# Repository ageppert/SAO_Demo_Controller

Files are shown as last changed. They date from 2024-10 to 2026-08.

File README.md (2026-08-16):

# SAO DEMO CONTROLLER

A Microcontroller for your smarter-than-average SAO!

The SAO Demo Controller makes it convenient to bring life to your advanced I2C-based SAO! Use this to test and demonstrate your new design even when your host badge isn't ready to control the SAO. Maybe this is better referred to as a micro badge for developing SAOs.

CAUTION: Do not plug this into your host badge and USB-C at the same time!!!

Follow this project at: https://hackaday.io/project/198034-sao-demo-controller 

Hardware Version 3.X
This one is protected for multiple power input options simultaneously with far more advanced power options, protection, and routing. This one is a perfect companion for an Etch sAo Sketch, Mac SAO, or any other SAO! See schematic for details and instructions.

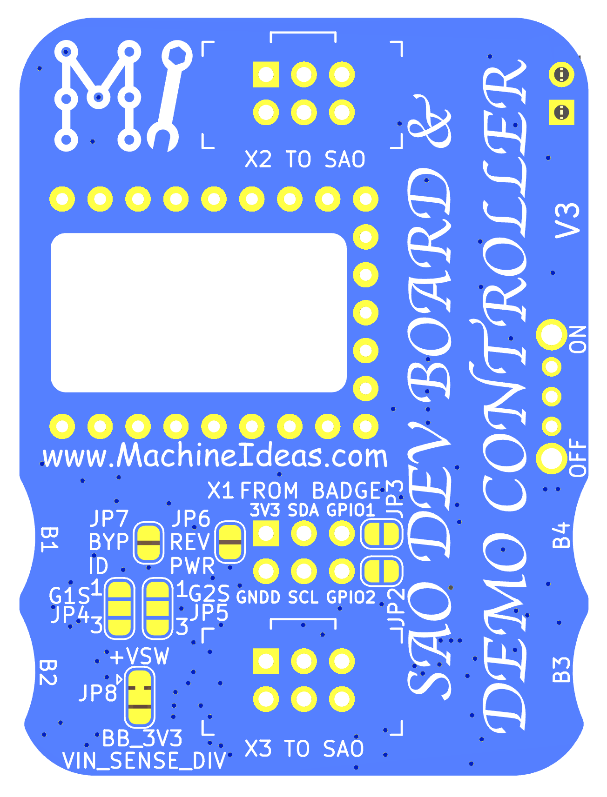
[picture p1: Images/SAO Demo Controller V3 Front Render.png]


Hardware Version 2.0 

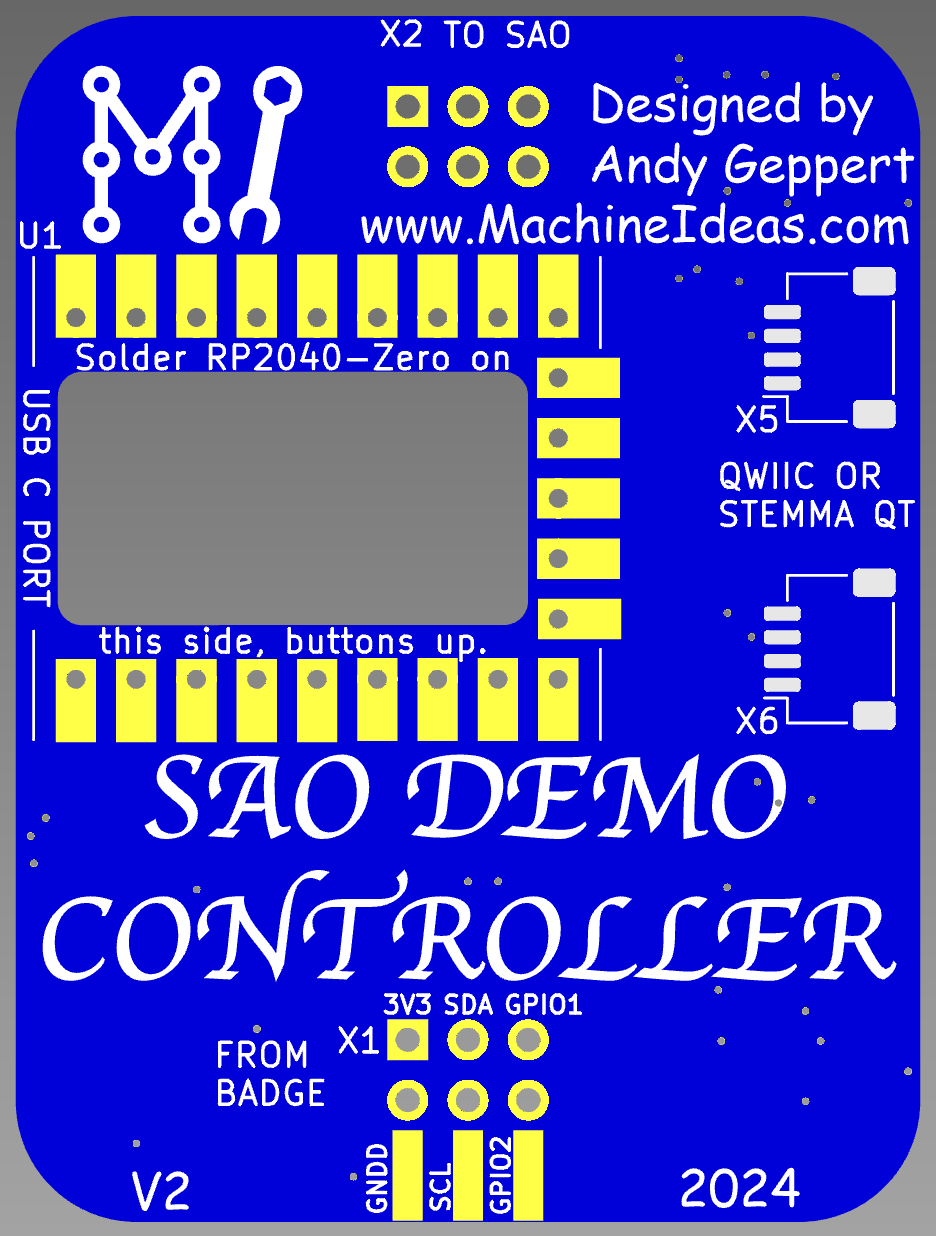
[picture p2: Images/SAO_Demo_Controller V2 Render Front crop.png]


Hardware Version 1.0 

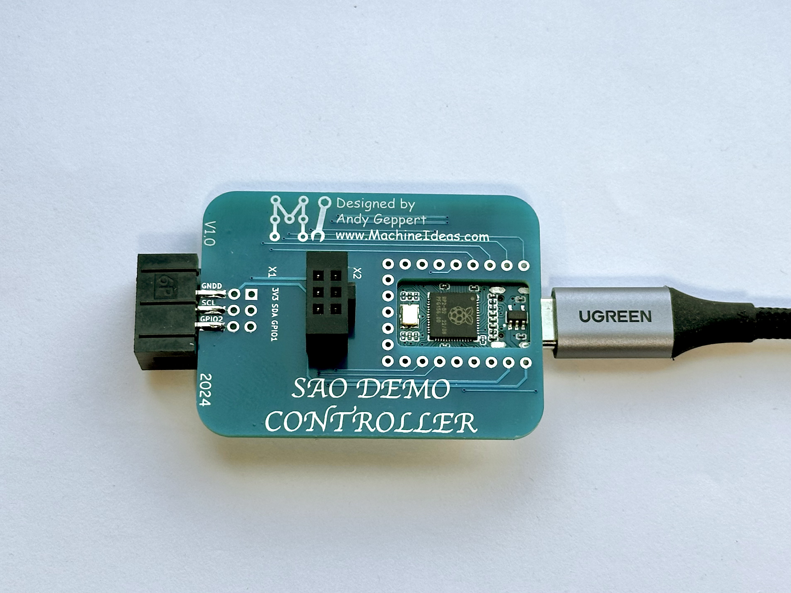
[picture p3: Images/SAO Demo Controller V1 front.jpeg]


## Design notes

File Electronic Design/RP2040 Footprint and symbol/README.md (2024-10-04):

# RP2040-Zero-KiCAD
KiCAD footprint and symbol for the RP2040 Zero

Currently untested! Use at your own risk. Pin numbers are kind of arbitrary since I couldn't find any official pin labels, so I put pin 1 at the top left. 

FROM: https://github.com/dj505/RP2040-Zero-KiCAD

MODIFIED AND TESTED: Andy Geppert, 2024

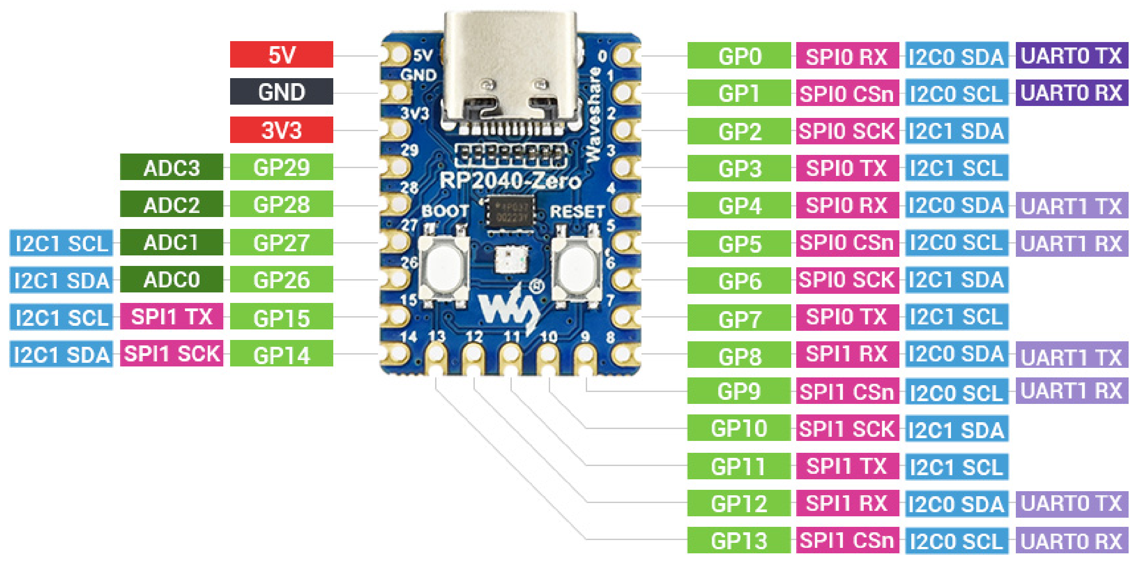
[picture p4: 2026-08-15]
Images/RP2040-Zero Pinout (top).png

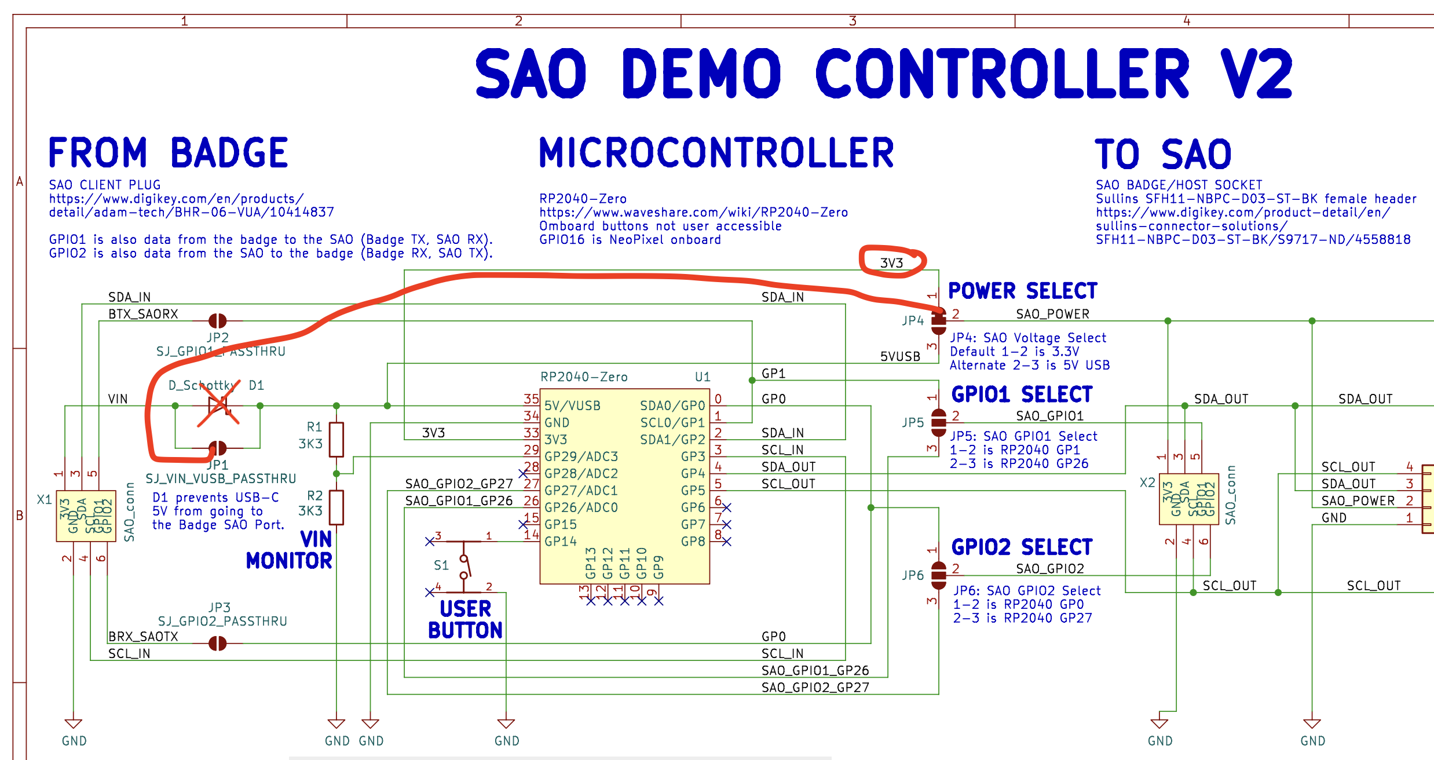
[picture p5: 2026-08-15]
Images/SAO Demo Controller mod for I2C1 on bottom schematic.png

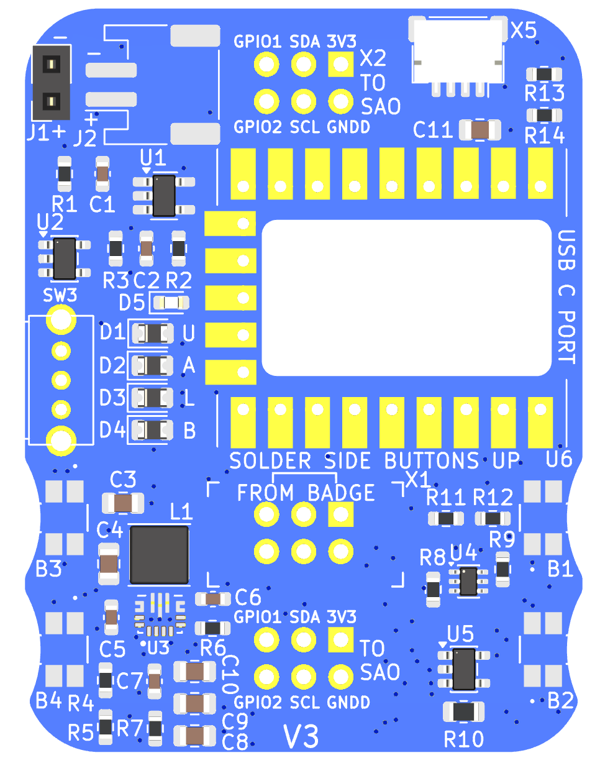
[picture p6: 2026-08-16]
Electronic Design/SAO Demo Controller V3 Schematic and Renders/SAO Demo Controller V3 Back Render.png

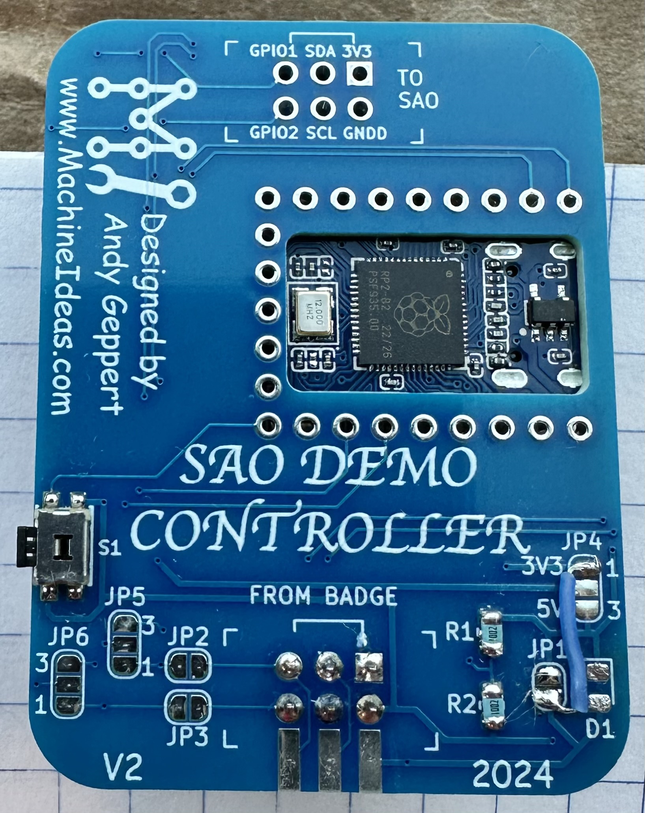
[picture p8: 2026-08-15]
Images/SAO Demo Controller mod for I2C1 on bottom pic.jpeg

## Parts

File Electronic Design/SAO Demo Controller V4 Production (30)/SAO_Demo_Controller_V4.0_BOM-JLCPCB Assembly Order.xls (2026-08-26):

JLCPCB BOM Tool - BOM Matching
BOM name：SAO_Demo_Controller_V4.0_bom-JLCPCB Assembly Order.xlsx |  |  | Download Time：2026-08-23 09:54:16 |  |  |  | * Our matching results are updated in real-time, but stock and prices may change. If it's been over 24 hours, please re-match before placing your order.
PCB Assembled Qty：30 |  |  | Est. Total Price：133.5422
Your BOM |  |  |  | Matched Parts |  |  |  |  |  |  | Order Information
Designator | Comment | Footprint | JLCPCB Part # | Matches | Part # | Manufacturer | Footprint | Description | Category | Warning | JLCPCB Part # | Product link | Lib Type | Qty | Source | Total Price ($)
B1,B2,B3,B4 | EVQP7J01P | SMD4_SW_EVQP7J_PAN |  | Select by System | EVQP7J01P | PANASONIC | SMD,3.6x3.5mm | -20℃~+70℃ 1.35mm 1.6N 100,000 cycles 12V 3.55mm 3.5mm 50mA Black Rectangular Button SMD(SMT) Tab SPST Surface Mount, Right Angle Without Bracket SMD,3.6x3.5mm Tactile Switches ROHS | Tactile Switches |  | C2828254 | https://jlcpcb.com/partdetail/PANASONIC-EVQP7J01P/C2828254 | Extended | 122 | 122 JLCPCB | 26.0348
C1,C5,C6 | 100nF | 0603 |  | Select by System | CC0603KRX7R9BB104 | YAGEO | 0603 | 100nF 50V X7R ±10% 0603 Multilayer Ceramic Capacitors MLCC - SMD/SMT ROHS | Multilayer Ceramic Capacitors MLCC - SMD/SMT |  | C14663 | https://jlcpcb.com/partdetail/YAGEO-CC0603KRX7R9BB104/C14663 | Basic | 100 | 100 JLCPCB | 1.5
C2,C7 | 10uF | 0603 |  | Select by System | CL10A106KP8NNNC | Samsung Electro-Mechanics | 0603 | 10V 10uF X5R ±10% 0603 Multilayer Ceramic Capacitors MLCC - SMD/SMT ROHS | Multilayer Ceramic Capacitors MLCC - SMD/SMT |  | C19702 | https://jlcpcb.com/partdetail/20411-CL10A106KP8NNNC/C19702 | Basic | 70 | 70 JLCPCB | 2.541
C3,C4 | 47uF | 0805 |  | Select by System | CL21A476MQYNNNE | Samsung Electro-Mechanics | 0805 | 47uF 6.3V X5R ±20% 0805 Multilayer Ceramic Capacitors MLCC - SMD/SMT ROHS | Multilayer Ceramic Capacitors MLCC - SMD/SMT |  | C16780 | https://jlcpcb.com/partdetail/17464-CL21A476MQYNNNE/C16780 | Basic | 66 | 66 JLCPCB | 11.5632
D1 | LED | 0603 |  | Select by System | KT-0603R | Hubei KENTO Elec | 0603 | -40℃~+85℃ 1.6mm x 0.8mm square LED 1.8V~2.4V 120° 20mA 300mcd 40mW 615nm~630nm 645nm Discrete Diode Red Water Clear 0603 LED Indication - Discrete ROHS | LED Indication - Discrete |  | C2286 | https://jlcpcb.com/partdetail/Hubei_KENTOElec-KT0603R/C2286 | Basic | 40 | 40 JLCPCB | 0.296
J2 | BAT-L | JST_PH_S2B-PH-SM4-TB_1x02-1MP_P2.00mm_Horizontal |  | Select by System | S2B-PH-SM4-TB(LF)(SN) | JST | SMD,P=2mm,卧贴 | -25℃~+85℃ 1 100V 1x2P 2 2A 2P 2mm 5.5mm 7.9mm 8.6mm Auxiliary Solder Pin Beige Copper alloy PA PH Surface Mount, Right Angle Tin UL94V-0 SMD,P=2mm,卧贴 Wire To Board Connector ROHS | Wire To Board Connector |  | C295747 | https://jlcpcb.com/partdetail/JST-S2B_PH_SM4_TB_LF_SN/C295747 | Extended | 30 | 30 JLCPCB | 6.495
L1 | 2.2uH | L_Sunlord_SWPA4020S |  | Select by System | SLW4018S2R2MST | Sunltech Tech | SMD,4x4mm | 1.65A 2.2uH 2.7A 45mΩ Magnetic Shielded Inductor ±20% SMD,4x4mm Power Inductors ROHS | Power Inductors |  | C206341 | https://jlcpcb.com/partdetail/SunltechTech-SLW4018S2R2MST/C206341 | Extended | 34 | 34 JLCPCB | 1.0608
R1,R15,R18,R4,R5,R6,R7 | 1K | 0603 |  | Select by System | 0603WAF1001T5E | UNI-ROYAL(Uniroyal Elec) | 0603 | -55℃~+155℃ 100mW 1kΩ 75V Thick Film Resistor ±1% ±100ppm/℃ 0603 Chip Resistor - Surface Mount ROHS | Chip Resistor - Surface Mount |  | C21190 | https://jlcpcb.com/partdetail/21904-0603WAF1001T5E/C21190 | Basic | 220 | 220 JLCPCB | 1.496
R2 | 1K2 | 0603 |  | Select by System | 0603WAF1201T5E | UNI-ROYAL(Uniroyal Elec) | 0603 | -55℃~+155℃ 1.2kΩ 100mW 75V Thick Film Resistor ±1% ±100ppm/℃ 0603 Chip Resistor - Surface Mount ROHS | Chip Resistor - Surface Mount |  | C22765 | https://jlcpcb.com/partdetail/23492-0603WAF1201T5E/C22765 | Basic | 40 | 40 JLCPCB | 0.252
R8,R9 | 2K2 | 0603 |  | Select by System | 0603WAF2201T5E | UNI-ROYAL(Uniroyal Elec) | 0603 | -55℃~+155℃ 100mW 2.2kΩ 75V Thick Film Resistor ±1% ±100ppm/℃ 0603 Chip Resistor - Surface Mount ROHS | Chip Resistor - Surface Mount |  | C4190 | https://jlcpcb.com/partdetail/4597-0603WAF2201T5E/C4190 | Basic | 70 | 70 JLCPCB | 0.287
R10 | 0 | 0603 |  | Select by System | 0603WAF0000T5E | UNI-ROYAL(Uniroyal Elec) | 0603 | -55℃~+155℃ 0Ω 100mW 75V Thick Film Resistor ±1% 0603 Chip Resistor - Surface Mount ROHS | Chip Resistor - Surface Mount |  | C21189 | https://jlcpcb.com/partdetail/21903-0603WAF0000T5E/C21189 | Basic | 40 | 40 JLCPCB | 0.156
R12 | 1.2M | 0603 |  | Select by System | 0603WAF1204T5E | UNI-ROYAL(Uniroyal Elec) | 0603 | 1.2MΩ ±1% 0603 Chip Resistor - Surface Mount ROHS | Chip Resistor - Surface Mount |  | C22766 | https://jlcpcb.com/partdetail/23493-0603WAF1204T5E/C22766 | Extended | 40 | 40 JLCPCB | 0.072
R13 | 210K | 0603 |  | Select by System | CQ03WAF2103T5E | UNI-ROYAL(Uniroyal Elec) | 0603 | -55℃~+155℃ 100mW 210kΩ Thick Film Resistor ±1% 0603 Chip Resistor - Surface Mount ROHS |  |  | C50670454 | https://jlcpcb.com/partdetail/53304519-CQ03WAF2103T5E/C50670454 | Extended | 36 | 36 JLCPCB | 0.0648
R14,R16 | 8K2 | 0603 |  | Select by System | 0603WAF8201T5E | UNI-ROYAL(Uniroyal Elec) | 0603 | -55℃~+155℃ 100mW 75V 8.2kΩ Thick Film Resistor ±1% ±100ppm/℃ 0603 Chip Resistor - Surface Mount ROHS | Chip Resistor - Surface Mount |  | C25981 | https://jlcpcb.com/partdetail/26724-0603WAF8201T5E/C25981 | Basic | 70 | 70 JLCPCB | 0.455
R17 | 0.05-1% | 0805 |  | Select by System | LRE0805-2CR050F5 | RALEC | 0805 | 500mW 50mΩ Alloy Resistor SMD ±1% 0805 Current Sense Resistors / Shunt Resistors ROHS | Current Sense Resistors / Shunt Resistors |  | C5141277 | https://jlcpcb.com/partdetail/RALEC-LRE08052CR050F5/C5141277 | Extended | 34 | 34 JLCPCB | 2.2338
R19,R20,R3 | 4K7 | 0603 |  | Select by System | 0603WAF4701T5E | UNI-ROYAL(Uniroyal Elec) | 0603 | -55℃~+155℃ 100mW 4.7kΩ 75V Thick Film Resistor ±1% ±100ppm/℃ 0603 Chip Resistor - Surface Mount ROHS | Chip Resistor - Surface Mount |  | C23162 | https://jlcpcb.com/partdetail/23889-0603WAF4701T5E/C23162 | Basic | 100 | 100 JLCPCB | 0.3
SW3 | SK12D07L4B | Switch_SK12D07VG4 |  | Select by System | SK12D07L4B | XKB Connection | 插件,8.6x4.5mm | -20℃~+80℃ 10000 times 300mA 4.5mm 4.7mm 50V 8.6mm Black PC Pin Rectangular Columnar SPDT 插件,8.6x4.5mm Slide Switches ROHS | Slide Switches |  | C480340 | https://jlcpcb.com/partdetail/XKBConnection-SK12D07L4B/C480340 | Extended | 30 | 30 JLCPCB | 2.973
U1 | RY2201 | SOT-23-5_HandSoldering |  | Select by System | RY2201 | RYCHIP Semiconductor Inc. | SOT-23-5 | -40℃~+85℃ 1 100nA 2.4V 3A Lithium Battery Not supported Protection IC Support SOT-23-5 Battery Management ROHS | Battery Management |  | C370889 | https://jlcpcb.com/partdetail/RYCHIP_Semiconductor_Inc-RY2201/C370889 | Extended | 34 | 34 JLCPCB | 0.8738
U2 | TP4054 | SOT-23-5 |  | Select by System | TP4054-42-SOT25R | TOPPOWER(Nanjing Extension Microelectronics) | SOT-23-5 | -40℃~+85℃ 1 4.2V 450mA 45uA 4V~9V Charging IC Lithium Battery Not supported Not supported SOT-23-5 Battery Management ROHS | Battery Management |  | C32574 | https://jlcpcb.com/partdetail/33539-TP4054_42SOT25R/C32574 | Extended | 32 | 32 JLCPCB | 5.5904
U3,U4,U5,U6,U8 | LM66100DCK | SOT-363_SC-70-6 |  | Select by System | LM66100DCKR | Texas Instruments | SC-70-6 | -40℃~+125℃ 1 1.5A 1.5V~5.5V 150nA 95mΩ Integrated FET Reverse current blocking、Reverse polarity protection、With enable SC-70-6 ORing Controllers ROHS | Power Distribution Switches |  | C2869734 | https://jlcpcb.com/partdetail/TexasInstruments-LM66100DCKR/C2869734 | Extended | 150 | 150 JLCPCB | 26.025
U7 | TPS61200DRC | Texas_S-PVSON-N10_ThermalVias |  | Select by System | TPS61200DRCR | Texas Instruments | VSON-10-EP(3x3) | -40℃~+85℃@(TA) 1 1.65MHz 1.8V~5.5V 300mV~5.5V 70uA Adjustable Boost Boost Built-in Yes VSON-10-EP(3x3) DC-DC Converters ROHS | DC-DC Converters |  | C140320 | https://jlcpcb.com/partdetail/TexasInstruments-TPS61200DRCR/C140320 | Extended | 30 | 30 JLCPCB | 32.694
U9 | INA180A2 | SOT-23-5 |  | Select by System | INA180A2IDBVR(LX) | lingxingic | SOT-23-5 | -200mV~30V -40℃~+125℃ 1 100dB 175uA 1uV/℃ 2.7V~5.5V 210kHz 25uV 40nV/√Hz@1kHz 4V/us 50V/V 75uA 8mA Bidirectional detection、Zero drift / auto-zero ±30V SOT-23-5 Current Sense Amplifiers ROHS | Current Sense Amplifiers |  | C48533471 | https://jlcpcb.com/partdetail/lingxingic-INA180A2IDBVR_LX/C48533471 | Extended | 32 | 32 JLCPCB | 4.1856
X4 | QWIIC | JST_SH_SM04B-SRSS-TB_1x04-1MP_P1.00mm_Horizontal |  | Select by System | SM04B-SRSS-TB(LF)(SN) | JST | SMD,P=1mm,卧贴 | -25℃~+85℃ 1 1A 1mm 1x4P 2.9mm 4 4.32mm 4P 50V 6mm Auxiliary Solder Pin Copper alloy PA SH Surface Mount, Right Angle Tin UL94V-0 White SMD,P=1mm,卧贴 Wire To Board Connector ROHS | Wire To Board Connector |  | C160404 | https://jlcpcb.com/partdetail/JST-SM04B_SRSS_TB_LF_SN/C160404 | Extended | 30 | 30 JLCPCB | 6.393

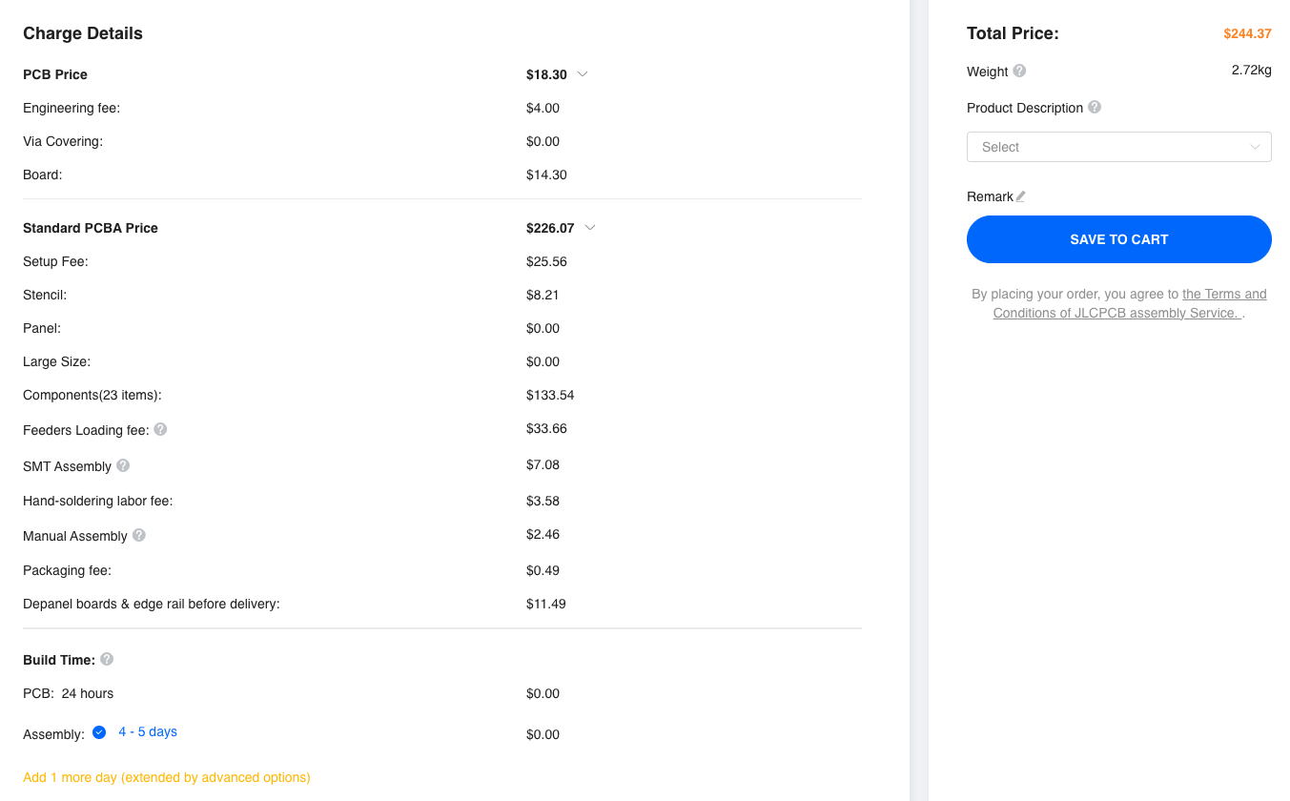
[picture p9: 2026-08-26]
Electronic Design/SAO Demo Controller V4 Production (30)/Cost overview.png

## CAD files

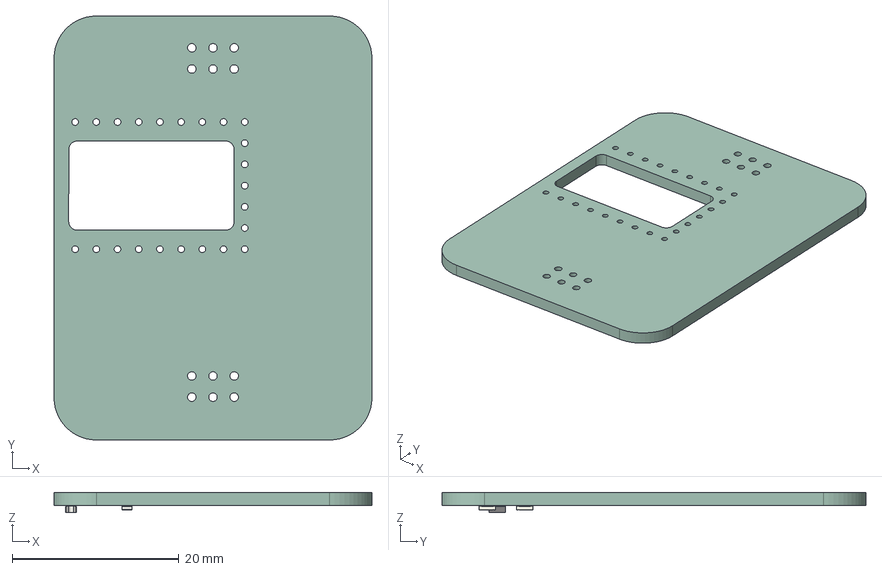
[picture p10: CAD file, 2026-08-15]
Electronic Design/SAO Demo Controller V2 Mechanical CAD/SAO_Demo_Controller_V2_PCB.step
38.1 x 50.8 x 2.45 mm
D_0805
R_0805_2012Metric x 2
SAO_Demo_Controller_PCB

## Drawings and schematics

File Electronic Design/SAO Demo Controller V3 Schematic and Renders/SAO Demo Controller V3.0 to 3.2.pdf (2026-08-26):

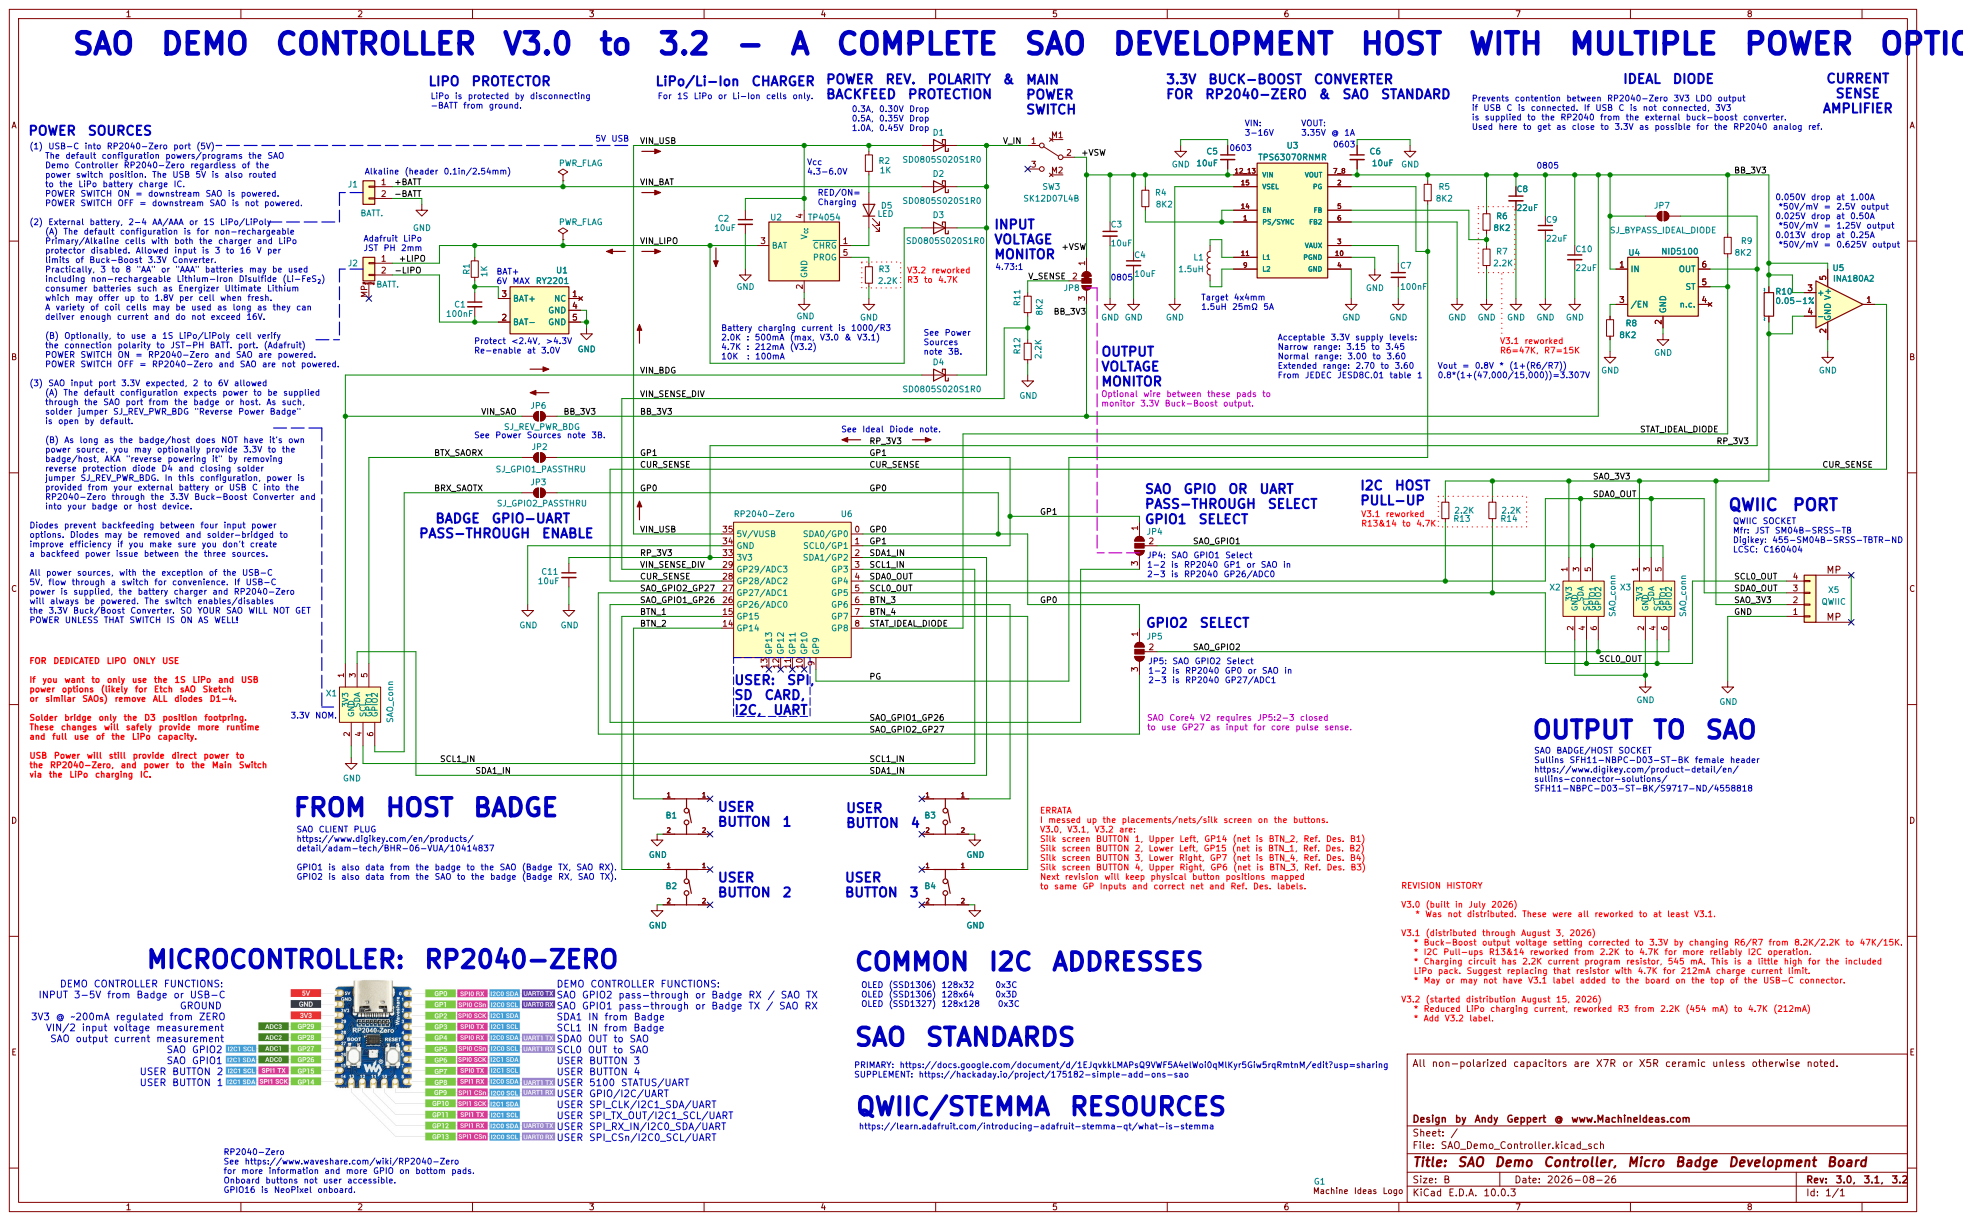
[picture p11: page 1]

SAO DEMO CONTROLLER V3.0 to 3.2 - A COMPLETE SAO DEVELOPMENT HOST WITH MULTIPLE POWER OPTIONS!

LiPo/Li-Ion CHARGER

V3.1 reworked R6=47K, R7=15K 3.3V BUCK-BOOST CONVERTER
FOR RP2040-ZERO & SAO STANDARD

LiPo is protected by disconnecting -BATT from ground.

See Ideal Diode note. See Power Sources note 3B. For 1S LiPo or Li-Ion cells only.

Prevents contention between RP2040-Zero 3V3 LDO output
if USB C is connected. If USB C is not connected, 3V3
is supplied to the RP2040 from the external buck-boost converter. Used here to get as close to 3.3V as possible for the RP2040 analog ref.

(1) USB-C into RP2040-Zero port (5V) The default configuration powers/programs the SAO

Demo Controller RP2040-Zero regardless of the power switch position. The USB 5V is also routed

to the LiPo battery charge IC. POWER SWITCH ON = downstream SAO is powered. POWER SWITCH OFF = downstream SAO is not powered.

*50V/mV = 2.5V output 0.025V drop at 0.50A

(2) External battery, 2-4 AA/AAA or 1S LiPo/LiPoly
(A) The default configuration is for non-rechargeable
Primary/Alkaline cells with both the charger and LiPo
protector disabled. Allowed input is 3 to 16 V per
limits of Buck-Boost 3.3V Converter. Practically, 3 to 8 "AA" or "AAA" batteries may be used

*50V/mV = 1.25V output 0.013V drop at 0.25A

including non-rechargeable Lithium-Iron Disulfide (Li-FeS₂) consumer batteries such as Energizer Ultimate Lithium

which may offer up to 1.8V per cell when fresh. A variety of coil cells may be used as long as they can

deliver enough current and do not exceed 16V. (B) Optionally, to use a 1S LiPo/LiPoly cell verify

Battery charging current is 1000/R3

Acceptable 3.3V supply levels: Narrow range: 3.15 to 3.45 Normal range: 3.00 to 3.60

the connection polarity to JST-PH BATT. port. (Adafruit) POWER SWITCH ON = RP2040-Zero and SAO are powered. POWER SWITCH OFF = RP2040-Zero and SAO are not powered.

(3) SAO input port 3.3V expected, 2 to 6V allowed
(A) The default configuration expects power to be supplied
through the SAO port from the badge or host. As such, solder jumper SJ_REV_PWR_BDG "Reverse Power Badge"

is open by default. (B) As long as the badge/host does NOT have it's own

power source, you may optionally provide 3.3V to the badge/host, AKA "reverse powering it" by removing

reverse protection diode D4 and closing solder
jumper SJ_REV_PWR_BDG. In this configuration, power is provided from your external battery or USB C into the RP2040-Zero through the 3.3V Buck-Boost Converter and

SAO GPIO OR UART
PASS-THROUGH SELECT

into your badge or host device. Diodes prevent backfeeding between four input power options. Diodes may be removed and solder-bridged to

QWIIC SOCKET Mfr: JST SM04B-SRSS-TB

improve efficiency if you make sure you don't create a backfeed power issue between the three sources. All power sources, with the exception of the USB-C 5V, flow through a switch for convenience. If USB-C

Digikey: 455-SM04B-SRSS-TBTR-ND
LCSC: C160404

power is supplied, the battery charger and RP2040-Zero will always be powered. The switch enables/disables

the 3.3V Buck/Boost Converter. SO YOUR SAO WILL NOT GET POWER UNLESS THAT SWITCH IS ON AS WELL!

to use GP27 as input for core pulse sense. JP5: SAO GPIO2 Select 1-2 is RP2040 GP0 or SAO in 2-3 is RP2040 GP27/ADC1

FOR DEDICATED LIPO ONLY USE
If you want to only use the 1S LiPo and USB
power options (likely for Etch sAO Sketch
or similar SAOs) remove ALL diodes D1-4. Solder bridge only the D3 position footpring. These changes will safely provide more runtime and full use of the LiPo capacity. USB Power will still provide direct power to

to same GP Inputs and correct net and Ref. Des. labels. SAO Core4 V2 requires JP5:2-3 closed

SAO BADGE/HOST SOCKET Sullins SFH11-NBPC-D03-ST-BK female header https://www.digikey.com/product-detail/en/

the RP2040-Zero, and power to the Main Switch

SDA1_IN | | SDA1_IN

SCL1_IN

SFH11-NBPC-D03-ST-BK/S9717-ND/4558818 REVISION HISTORY

ERRATA
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

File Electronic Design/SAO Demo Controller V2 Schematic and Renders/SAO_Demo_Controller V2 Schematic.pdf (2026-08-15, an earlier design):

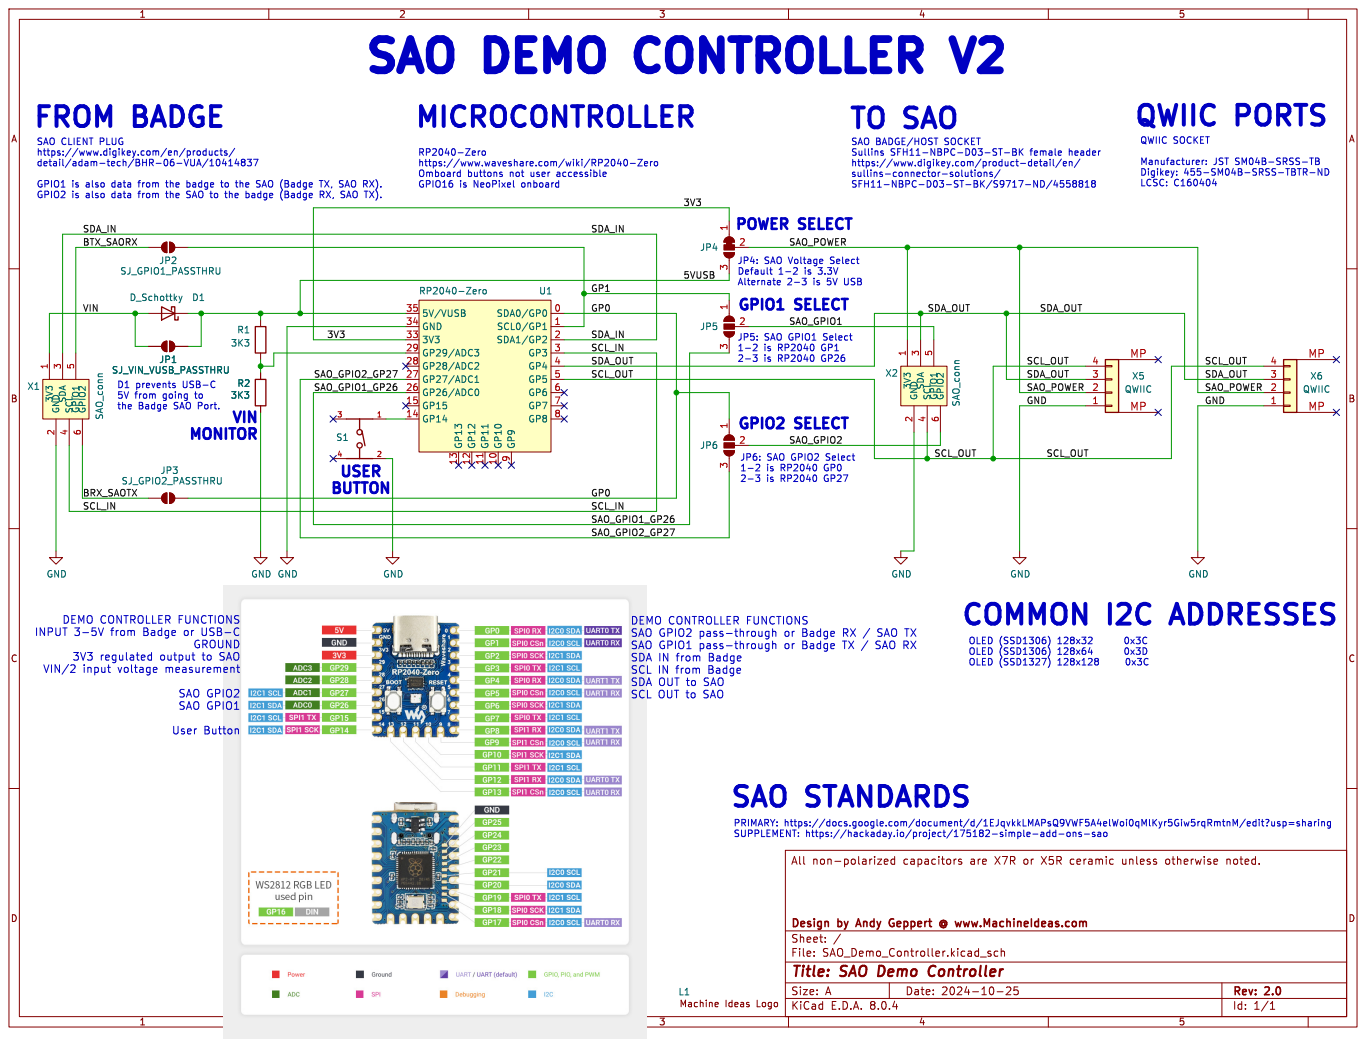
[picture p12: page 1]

https://www.waveshare.com/wiki/RP2040-Zero Omboard buttons not user accessible GPIO16 is NeoPixel onboard SAO DEMO CONTROLLER V2

SAO CLIENT PLUG
https://www.digikey.com/en/products/ detail/adam-tech/BHR-06-VUA/10414837 GPIO1 is also data from the badge to the SAO (Badge TX, SAO RX). GPIO2 is also data from the SAO to the badge (Badge RX, SAO TX).

SCL_OUT SAO_GPIO2 SAO_GPIO2_GP27 D1 prevents USB-C
5V from going to
the Badge SAO Port. VIN

DEMO CONTROLLER FUNCTIONS
INPUT 3-5V from Badge or USB-C GROUND

SDA IN from Badge SCL IN from Badge SDA OUT to SAO

SCL OUT to SAO

PRIMARY: https://docs.google.com/document/d/1EJqvkkLMAPsQ9VWF5A4elWoi0qMlKyr5Giw5rqRmtnM/edit?usp=sharing SUPPLEMENT: https://hackaday.io/project/175182-simple-add-ons-sao

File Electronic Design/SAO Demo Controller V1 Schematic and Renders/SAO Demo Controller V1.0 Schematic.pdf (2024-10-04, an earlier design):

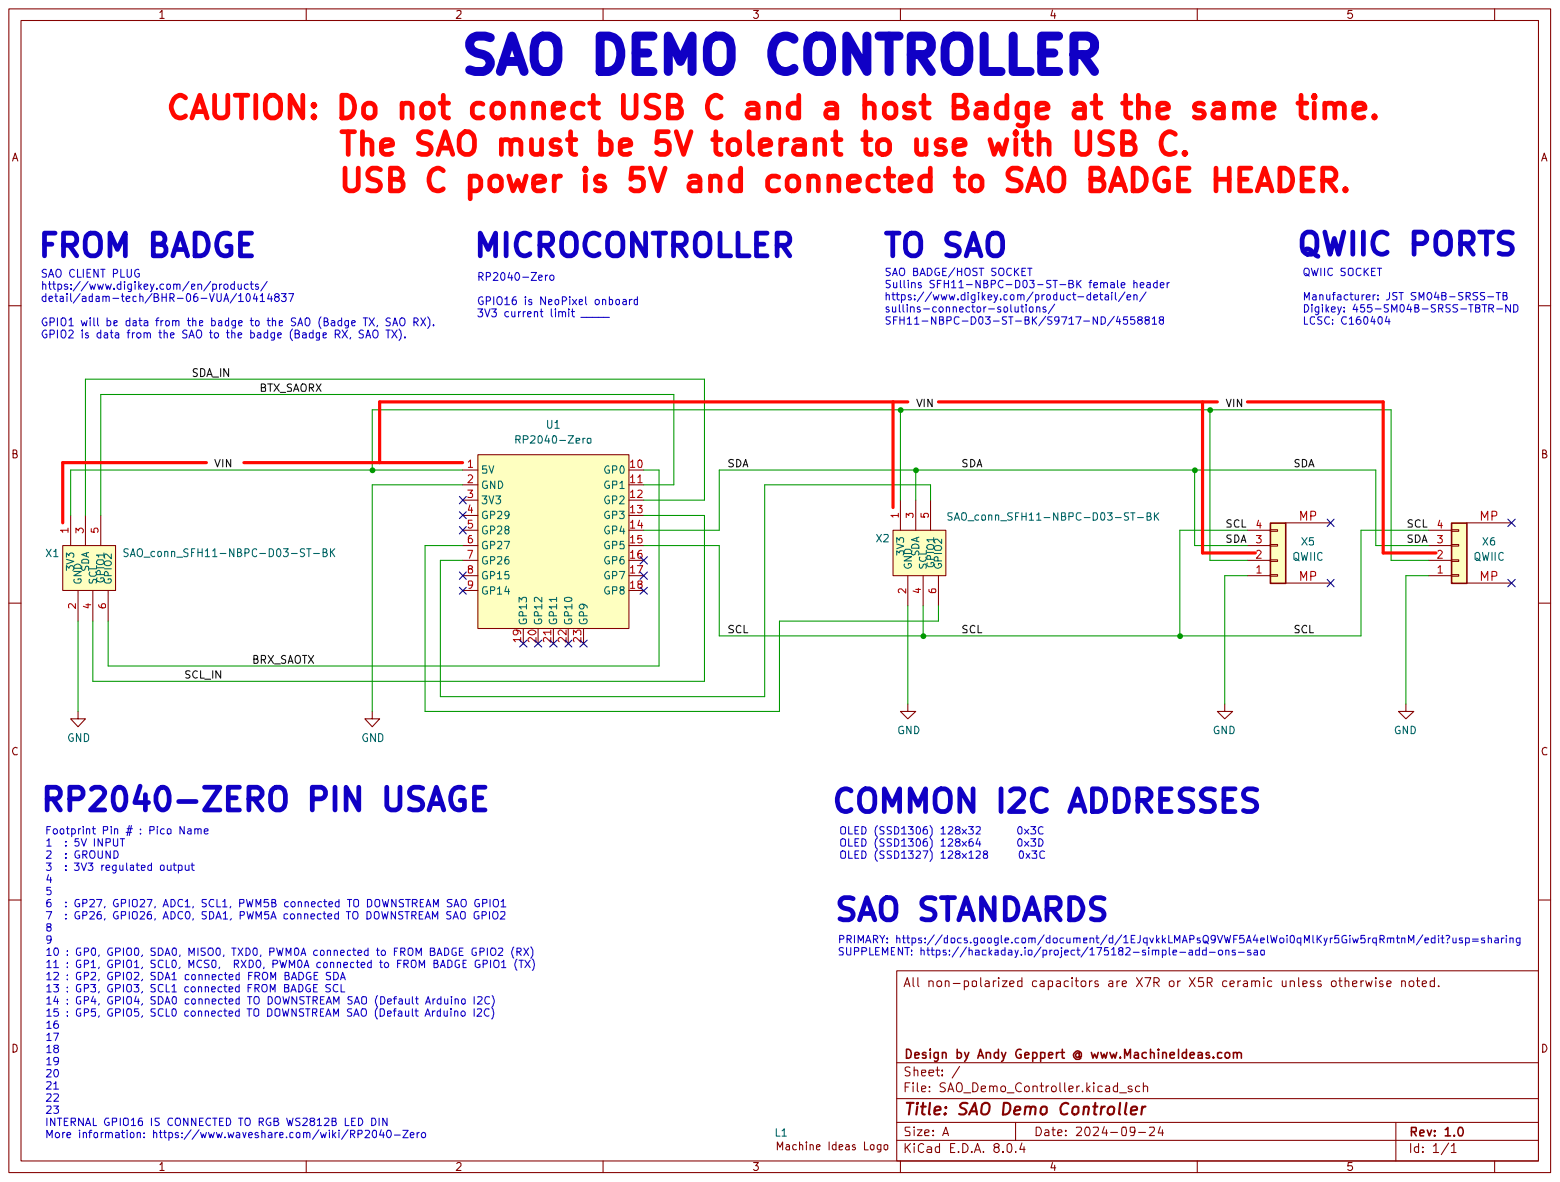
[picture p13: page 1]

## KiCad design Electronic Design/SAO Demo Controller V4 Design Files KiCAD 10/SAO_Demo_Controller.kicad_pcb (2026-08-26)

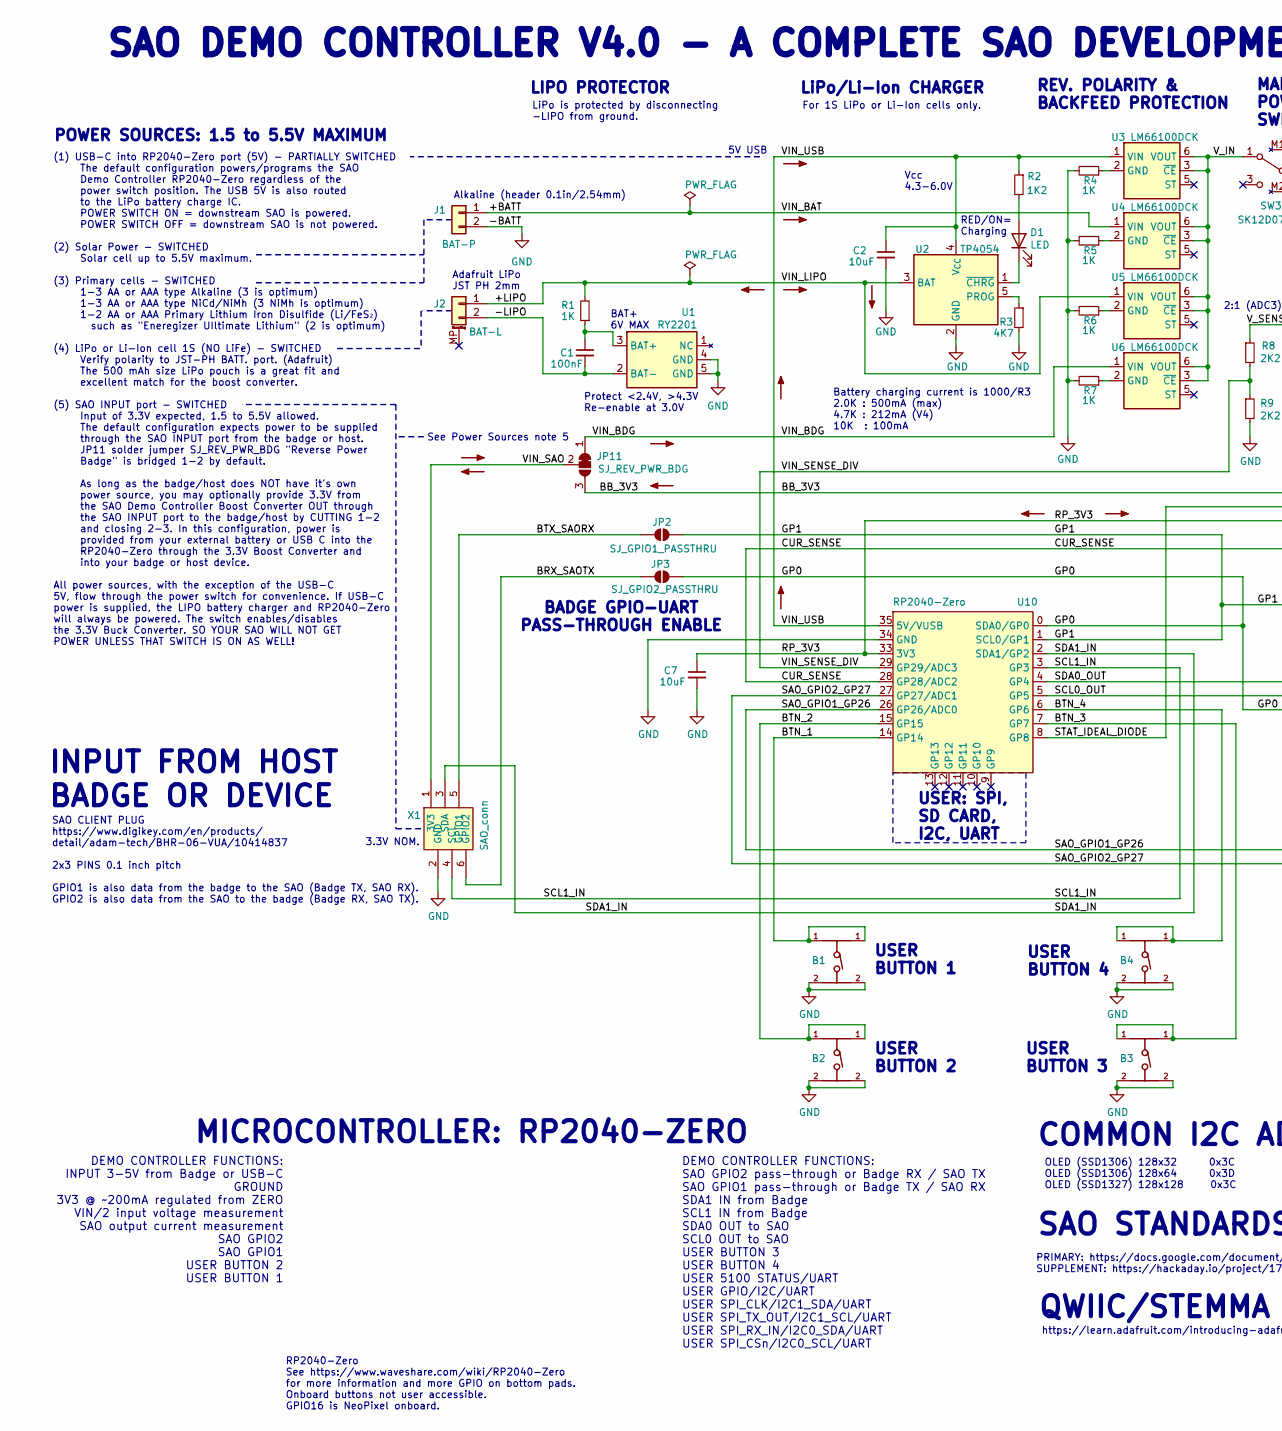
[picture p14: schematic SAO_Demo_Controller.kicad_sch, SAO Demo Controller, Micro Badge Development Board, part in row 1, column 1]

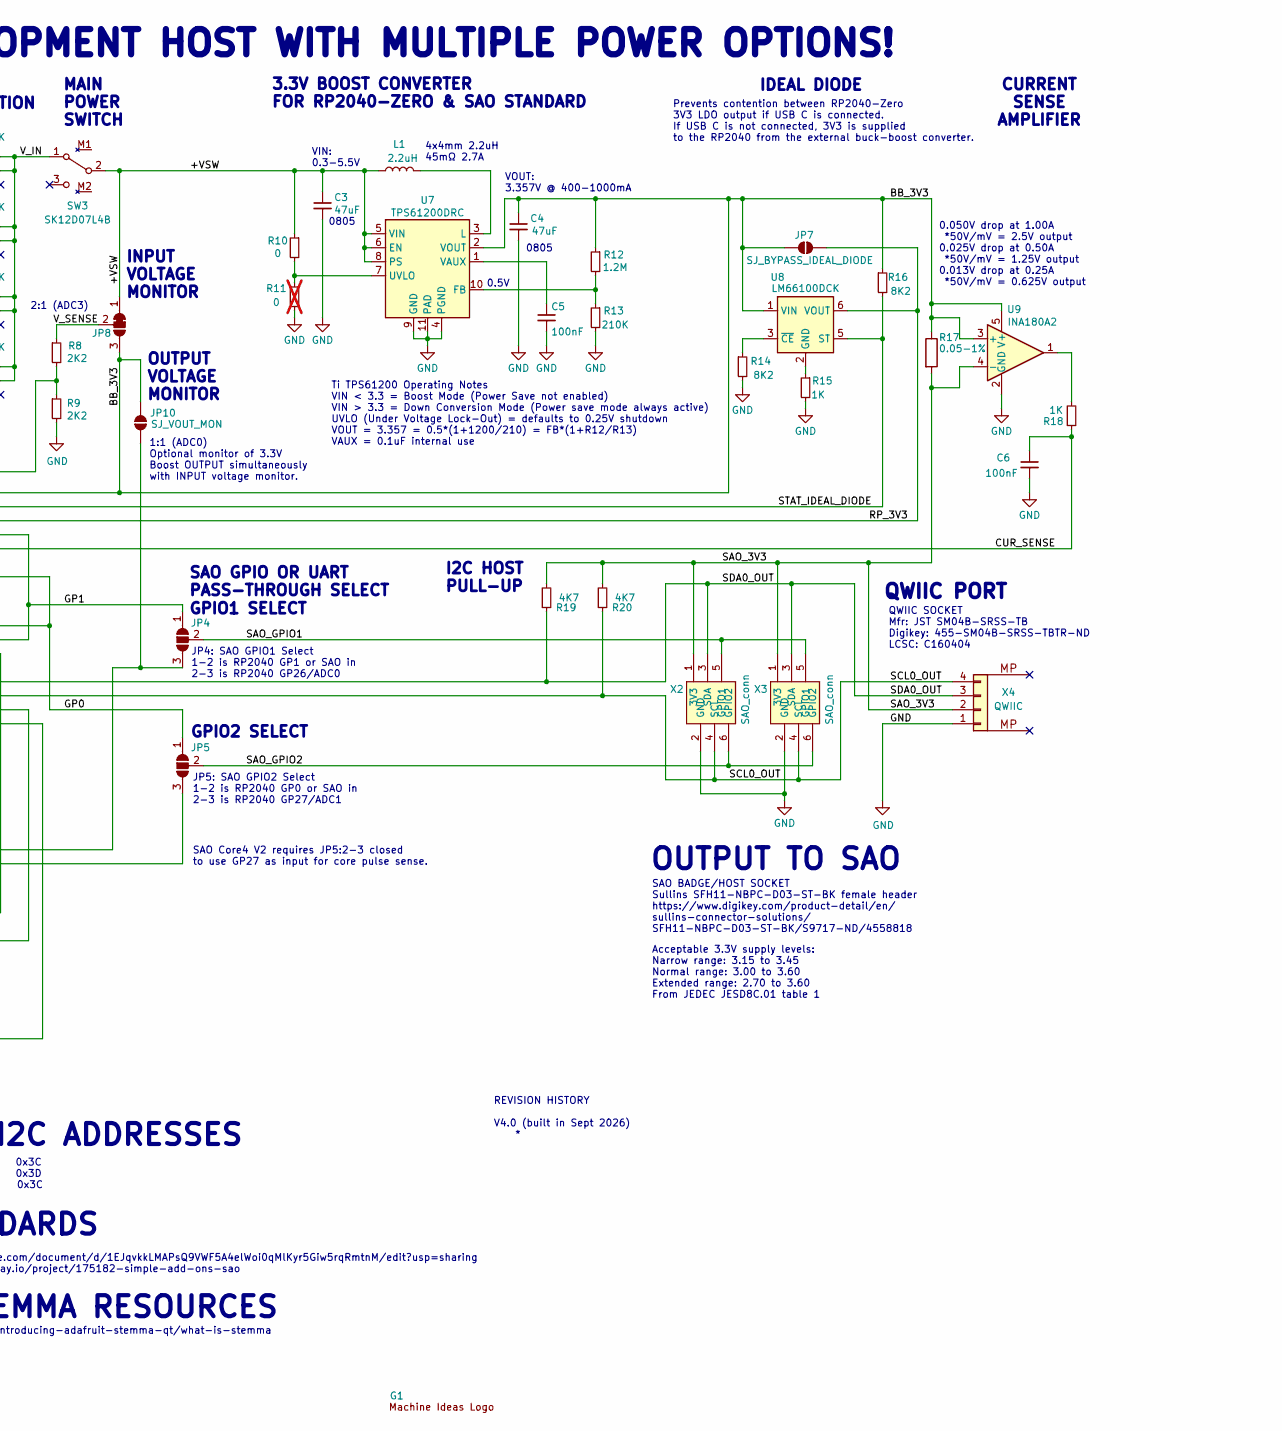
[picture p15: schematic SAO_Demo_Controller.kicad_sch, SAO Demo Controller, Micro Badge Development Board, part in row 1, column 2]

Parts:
B1, B2, B3, B4: EVQP7J01P; SMD4_SW_EVQP7J_PAN; LCSC C2828254
C1, C5, C6: 100nF; C_0603_1608Metric; LCSC C14663
C2, C7: 10uF; C_0603_1608Metric; LCSC C19702
C3, C4: 47uF; C_0805_2012Metric; PART-NUMBER 10V 47uF X5R ±20% 0805; LCSC C16780
D1: LED; LED_0603_1608Metric; LCSC C2286
G1: Machine_Ideas_logo
J1: BAT-P; PinSocket_1x02_P2.54mm_Vertical
J2: BAT-L; JST_PH_S2B-PH-SM4-TB_1x02-1MP_P2.00mm_Horizontal; LCSC C295747
JP2: SJ_GPIO1_PASSTHRU; SolderJumper-2_P1.3mm_Open_RoundedPad1.0x1.5mm
JP3: SJ_GPIO2_PASSTHRU; SolderJumper-2_P1.3mm_Open_RoundedPad1.0x1.5mm
JP4, JP5: SolderJumper_3_Open; SolderJumper-3_P1.3mm_Open_RoundedPad1.0x1.5mm_NumberLabels
JP7: SJ_BYPASS_IDEAL_DIODE; SolderJumper-2_P1.3mm_Open_RoundedPad1.0x1.5mm
JP8: SolderJumper_3_Open; SolderJumper-3_P1.3mm_Bridged12_RoundedPad1.0x1.5mm
JP10: SJ_VOUT_MON; SolderJumper-2_P1.3mm_Open_RoundedPad1.0x1.5mm
JP11: SJ_REV_PWR_BDG; SolderJumper-3_P1.3mm_Bridged12_RoundedPad1.0x1.5mm
L1: 2.2uH; L_Sunlord_SWPA4020S; PART-NUMBER Sunltech Tech SLW4018S2R2MST; LCSC C206341
R1, R4, R5, R6, R7, R15, R18: 1K; R_0603_1608Metric; LCSC C21190
R2: 1K2; R_0603_1608Metric; LCSC C22765
R3, R19, R20: 4K7; R_0603_1608Metric; LCSC C23162
R8, R9: 2K2; R_0603_1608Metric; Manufacturer_Part_Number 0603WAF2201T5E; LCSC C4190
R10: 0; R_0603_1608Metric; LCSC C21189
R11: 0; R_0603_1608Metric; LCSC C21189; not fitted
R12: 1.2M; R_0603_1608Metric; LCSC C22766
R13: 210K; R_0603_1608Metric; LCSC C50670454
R14, R16: 8K2; R_0603_1608Metric; LCSC C25981
R17: 0.05-1%; R_0805_2012Metric; LCSC C5141277
SW3: SK12D07L4B; Switch_SK12D07VG4; LCSC C480340
U1: RY2201; SOT-23-5_HandSoldering; LCSC C370889
U2: TP4054; SOT-23-5; LCSC C32574
U3, U4, U5, U6, U8: LM66100DCK; SOT-363_SC-70-6; LCSC C2869734
U7: TPS61200DRC; Texas_S-PVSON-N10_ThermalVias; LCSC C140320
U9: INA180A2; SOT-23-5; LCSC C48533471
U10: RP2040-Zero; RP2040 Zero
X1: SAO_conn; Badgelife-SAOv169-BADGE-2x3-no-front-text; MPN SFH11-NBPC-D03-ST-BK
X2, X3: SAO_conn; Badgelife-SAOv169-BADGE-2x3-no-front-text-yes-front-outline; MPN SFH11-NBPC-D03-ST-BK
X4: QWIIC; JST_SH_SM04B-SRSS-TB_1x04-1MP_P1.00mm_Horizontal; MPN SM04B-SRSS-TB; LCSC C160404

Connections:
/+BATT: J1.1, U4.1 (VIN)
/+LIPO: J2.1, R1.2, U2.3 (BAT), U5.1 (VIN)
/+VSW: C3.1, JP8.1 (A), L1.2, R10.1, SW3.2 (B), U7.5 (VIN), U7.6 (EN), U7.8 (PS)
/-LIPO: C1.2, J2.2, U1.2 (BAT-)
/BB_3V3: C4.1, JP7.1 (A), JP8.3 (B), JP10.2 (B), JP11.3 (B), R12.1, R16.1, R17.1, U7.2 (VOUT), U8.1 (VIN), U9.3 (+), U9.5 (V+)
/BRX_SAOTX: JP3.1 (A), X1.6 (GPIO2)
/BTN_1: B1.1, U10.14 (GP14)
/BTN_2: B2.1, U10.15 (GP15)
/BTN_3: B3.1, U10.7 (GP7)
/BTN_4: B4.1, U10.6 (GP6)
/BTX_SAORX: JP2.1 (A), X1.5 (GPIO1)
/CUR_SENSE: C6.1, R18.1, U10.28 (GP28/ADC2)
/GP0: JP3.2 (B), JP5.1 (A), U10.0 (SDA0/GP0)
/GP1: JP2.2 (B), JP4.1 (A), U10.1 (SCL0/GP1)
/RP_3V3: C7.1, JP7.2 (B), U8.6 (VOUT), U10.33 (3V3)
/SAO_3V3: R17.2, R19.2, R20.2, U9.4 (-), X2.1 (3V3), X3.1 (3V3), X4.2
/SAO_GPIO1: JP4.2 (C), X2.5 (GPIO1), X3.5 (GPIO1)
/SAO_GPIO1_GP26: JP4.3 (B), JP10.1 (A), U10.26 (GP26/ADC0)
/SAO_GPIO2: JP5.2 (C), X2.6 (GPIO2), X3.6 (GPIO2)
/SAO_GPIO2_GP27: JP5.3 (B), U10.27 (GP27/ADC1)
/SCL0_OUT: R20.1, U10.5 (GP5), X2.4 (SCL), X3.4 (SCL), X4.4
/SCL1_IN: U10.3 (GP3), X1.4 (SCL)
/SDA0_OUT: R19.1, U10.4 (GP4), X2.3 (SDA), X3.3 (SDA), X4.3
/SDA1_IN: U10.2 (SDA1/GP2), X1.3 (SDA)
/STAT_IDEAL_DIODE: R16.2, U8.5 (ST), U10.8 (GP8)
/VIN_BDG: JP11.1 (A), U6.1 (VIN)
/VIN_SAO: JP11.2 (C), X1.1 (3V3)
/VIN_SENSE_DIV: R8.2, R9.1, U10.29 (GP29/ADC3)
/VIN_USB: C2.1, R2.1, U2.4 (V_{CC}), U3.1 (VIN), U10.35 (5V/VUSB)
/V_IN: SW3.1 (A), U3.3 (~CE), U3.6 (VOUT), U4.3 (~CE), U4.6 (VOUT), U5.3 (~CE), U5.6 (VOUT), U6.3 (~CE), U6.6 (VOUT)
/V_SENSE: JP8.2 (C), R8.1
GND: B1.2, B2.2, B3.2, B4.2, C2.2, C3.2, C4.2, C5.2, C6.2, C7.2, J1.2, R3.2, R4.2, R5.2, R6.2, R7.2, R9.2, R11.2, R13.2, R14.2, R15.2, U1.4 (GND), U1.5 (GND), U2.2 (GND), U7.4 (PGND), U7.9 (GND), U7.11 (PAD), U9.2 (GND), U10.34 (GND), X1.2 (GND), X2.2 (GND), X3.2 (GND), X4.1
unnamed: D1.2 (A), R2.2
unnamed: D1.1 (K), U2.1 (~CHRG)
unnamed: R18.2, U9.1
unnamed: C1.1, R1.1, U1.3 (BAT+)
unnamed: R3.1, U2.5 (PROG)
unnamed: R4.1, U3.2 (GND)
unnamed: R5.1, U4.2 (GND)
unnamed: R6.1, U5.2 (GND)
unnamed: R7.1, U6.2 (GND)
unnamed: R12.2, R13.1, U7.10 (FB)
unnamed: L1.1, U7.3 (L)
unnamed: R10.2, R11.1, U7.7 (UVLO)
unnamed: C5.1, U7.1 (VAUX)
unnamed: R15.1, U8.2 (GND)
unnamed: R14.1, U8.3 (~CE)

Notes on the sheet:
5V USB
REV. POLARITY & BACKFEED PROTECTION
SAO GPIO OR UART PASS-THROUGH SELECT
DEMO CONTROLLER FUNCTIONS: INPUT 3-5V from Badge or USB-C GROUND 3V3 @ ~200mA regulated from ZERO VIN/2 input voltage measurement SAO output current measurement SAO GPIO2 SAO GPIO1 USER BUTTON 2 USER BUTTON 1
Battery charging current is 1000/R3 2.0K : 500mA (max) 4.7K : 212mA (V4) 10K : 100mA
VOUT: 3.357V @ 400-1000mA
SAO BADGE/HOST SOCKET Sullins SFH11-NBPC-D03-ST-BK female header https://www.digikey.com/product-detail/en/ sullins-connector-solutions/ SFH11-NBPC-D03-ST-BK/S9717-ND/4558818
For 1S LiPo or Li-Ion cells only.
USER BUTTON 2
COMMON I2C ADDRESSES
QWIIC SOCKET Mfr: JST SM04B-SRSS-TB Digikey: 455-SM04B-SRSS-TBTR-ND LCSC: C160404
MAIN POWER SWITCH
USER BUTTON 1
Ti TPS61200 Operating Notes VIN < 3.3 = Boost Mode (Power Save not enabled) VIN > 3.3 = Down Conversion Mode (Power save mode always active) UVLO (Under Voltage Lock-Out) = defaults to 0.25V shutdown VOUT = 3.357 = 0.5*(1+1200/210) = FB*(1+R12/R13) VAUX = 0.1uF internal use
RP2040-Zero See https://www.waveshare.com/wiki/RP2040-Zero for more information and more GPIO on bottom pads. Onboard buttons not user accessible. GPIO16 is NeoPixel onboard.
USER: SPI, SD CARD, I2C, UART
GPIO1 SELECT
https://learn.adafruit.com/introducing-adafruit-stemma-qt/what-is-stemma
Acceptable 3.3V supply levels: Narrow range: 3.15 to 3.45 Normal range: 3.00 to 3.60 Extended range: 2.70 to 3.60 From JEDEC JESD8C.01 table 1
USER BUTTON 4
DEMO CONTROLLER FUNCTIONS: SAO GPIO2 pass-through or Badge RX / SAO TX SAO GPIO1 pass-through or Badge TX / SAO RX SDA1 IN from Badge SCL1 IN from Badge SDA0 OUT to SAO SCL0 OUT to SAO USER BUTTON 3 USER BUTTON 4 USER 5100 STATUS/UART USER GPIO/I2C/UART USER SPI_CLK/I2C1_SDA/UART USER SPI_TX_OUT/I2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
0805
0.050V drop at 1.00A *50V/mV = 2.5V output 0.025V drop at 0.50A *50V/mV = 1.25V output 0.013V drop at 0.25A *50V/mV = 0.625V output
SAO CLIENT PLUG https://www.digikey.com/en/products/ detail/adam-tech/BHR-06-VUA/10414837 2x3 PINS 0.1 inch pitch GPIO1 is also data from the badge to the SAO (Badge TX, SAO RX). GPIO2 is also data from the SAO to the badge (Badge RX, SAO TX).
3.3V NOM.
OLED (SSD1306) 128x32 0x3C OLED (SSD1306) 128x64 0x3D OLED (SSD1327) 128x128 0x3C
INPUT FROM HOST BADGE OR DEVICE
4x4mm 2.2uH 45mΩ 2.7A
Alkaline (header 0.1in/2.54mm)
BAT+ 6V MAX
QWIIC/STEMMA RESOURCES
IDEAL DIODE
RED/ON= Charging
SAO STANDARDS
Adafruit LiPo JST PH 2mm
I2C HOST PULL-UP
LIPO PROTECTOR
REVISION HISTORY V4.0 (built in Sept 2026) *
PRIMARY: https://docs.google.com/document/d/1EJqvkkLMAPsQ9VWF5A4elWoi0qMlKyr5Giw5rqRmtnM/edit?usp=sharing SUPPLEMENT: https://hackaday.io/project/175182-simple-add-ons-sao
INPUT VOLTAGE MONITOR

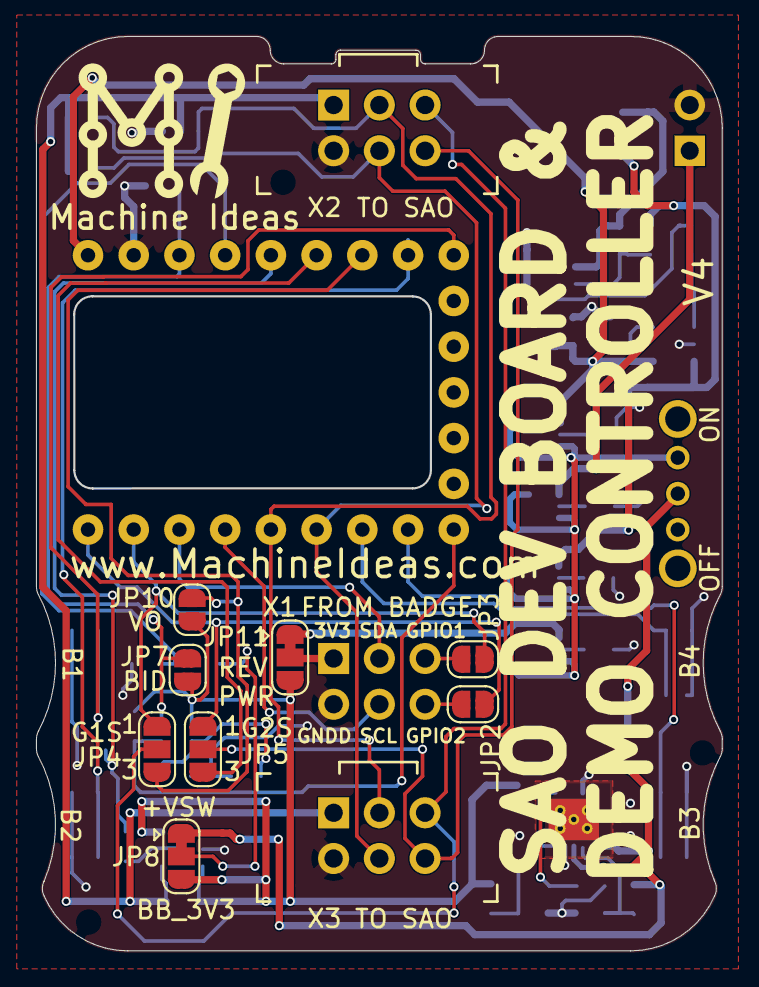
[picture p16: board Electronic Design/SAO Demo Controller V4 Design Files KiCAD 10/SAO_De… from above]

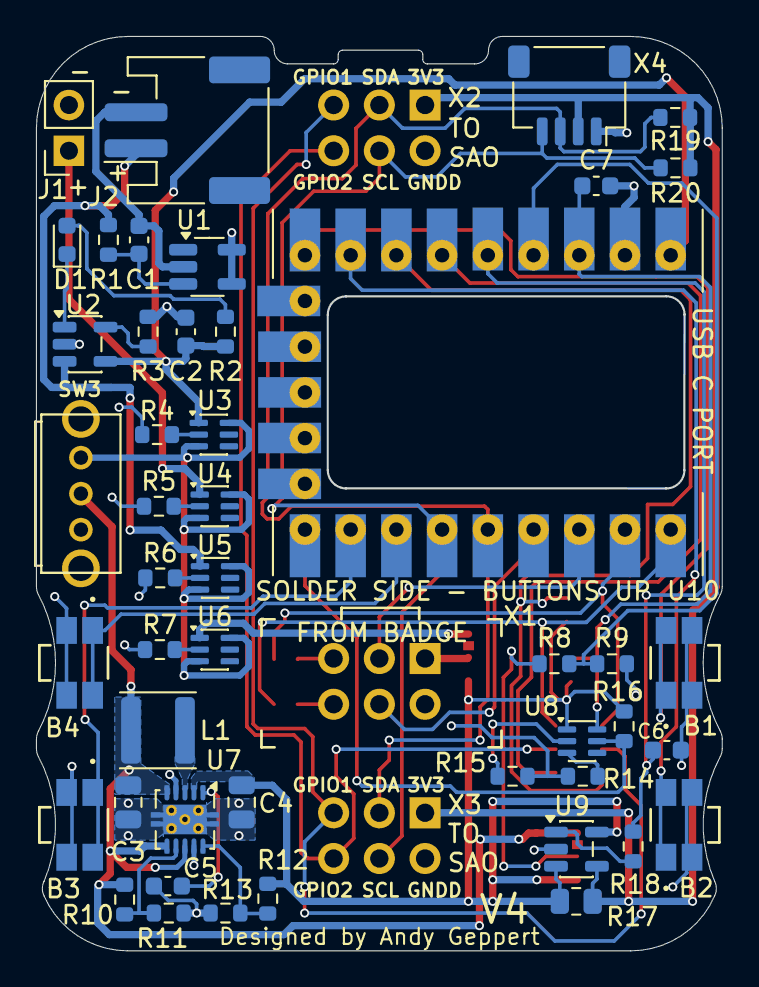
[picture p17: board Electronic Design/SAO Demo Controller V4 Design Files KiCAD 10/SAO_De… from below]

Board: 2 copper layers, 38.1 x 50.8 mm, 59 parts (47 on the bottom side), 47 nets.

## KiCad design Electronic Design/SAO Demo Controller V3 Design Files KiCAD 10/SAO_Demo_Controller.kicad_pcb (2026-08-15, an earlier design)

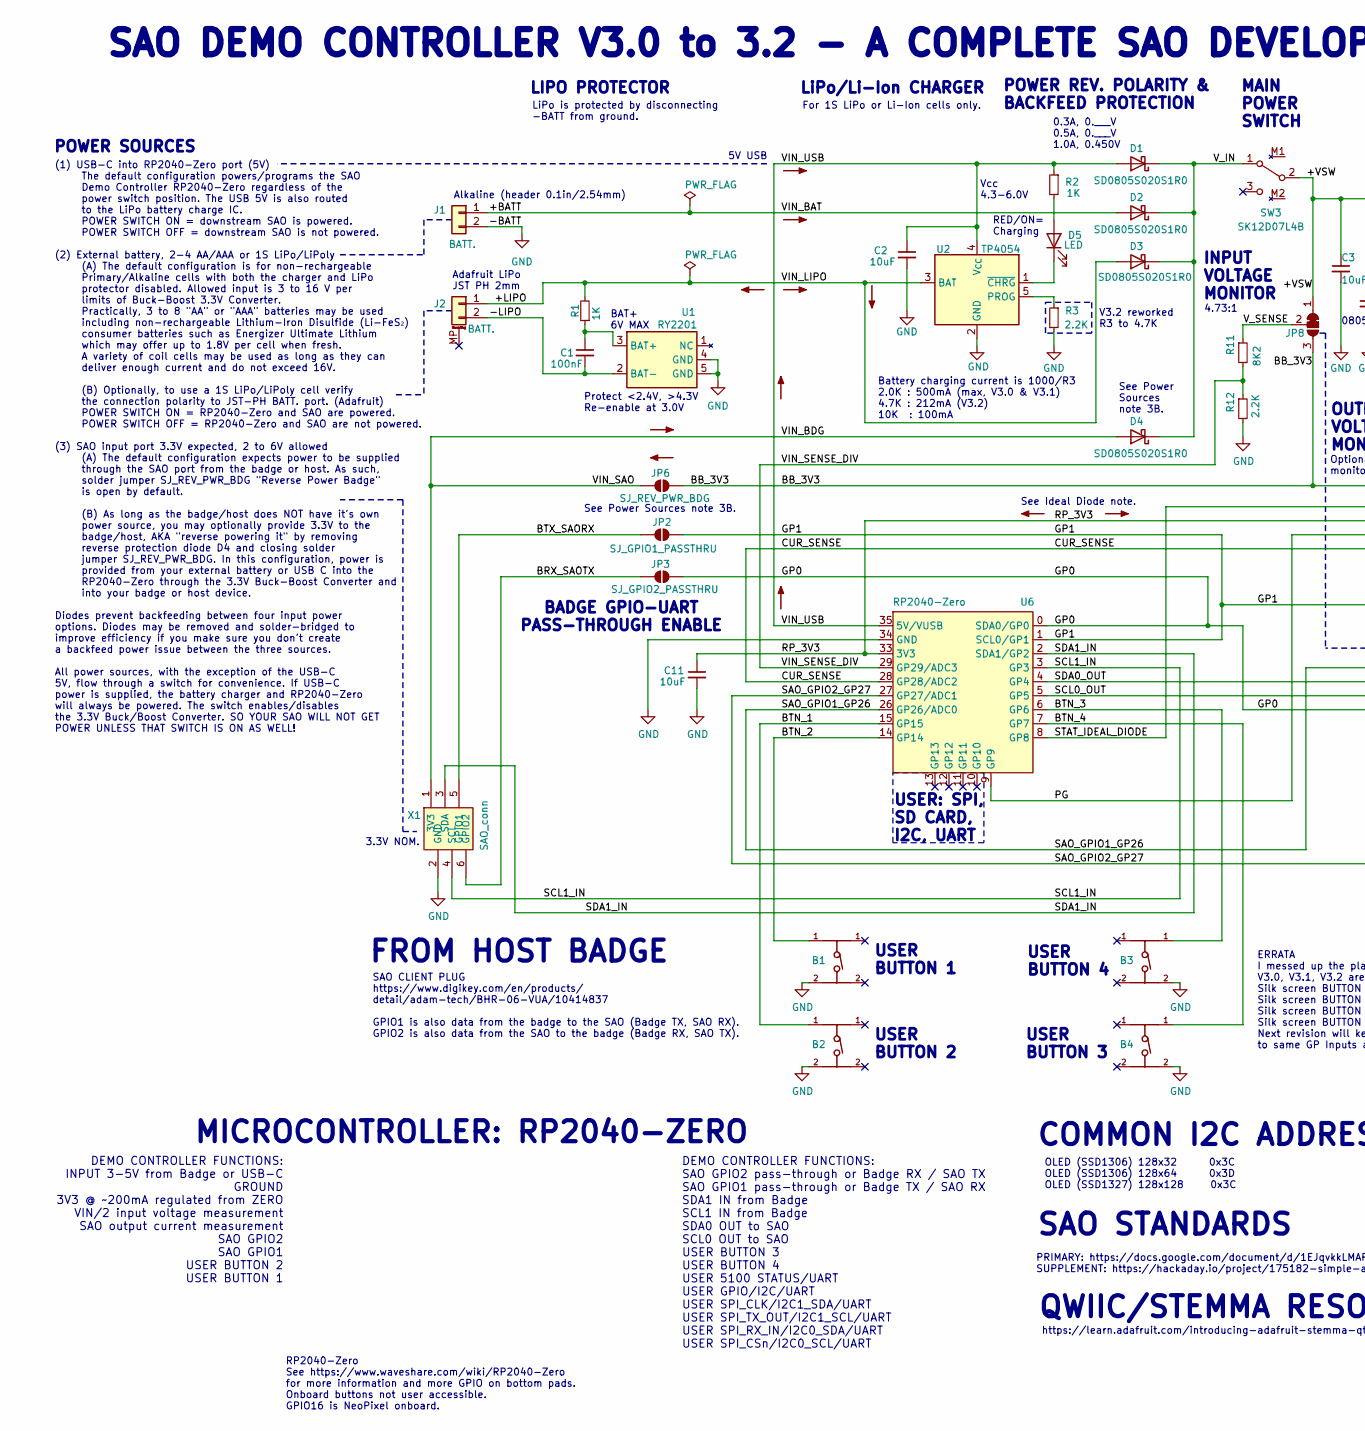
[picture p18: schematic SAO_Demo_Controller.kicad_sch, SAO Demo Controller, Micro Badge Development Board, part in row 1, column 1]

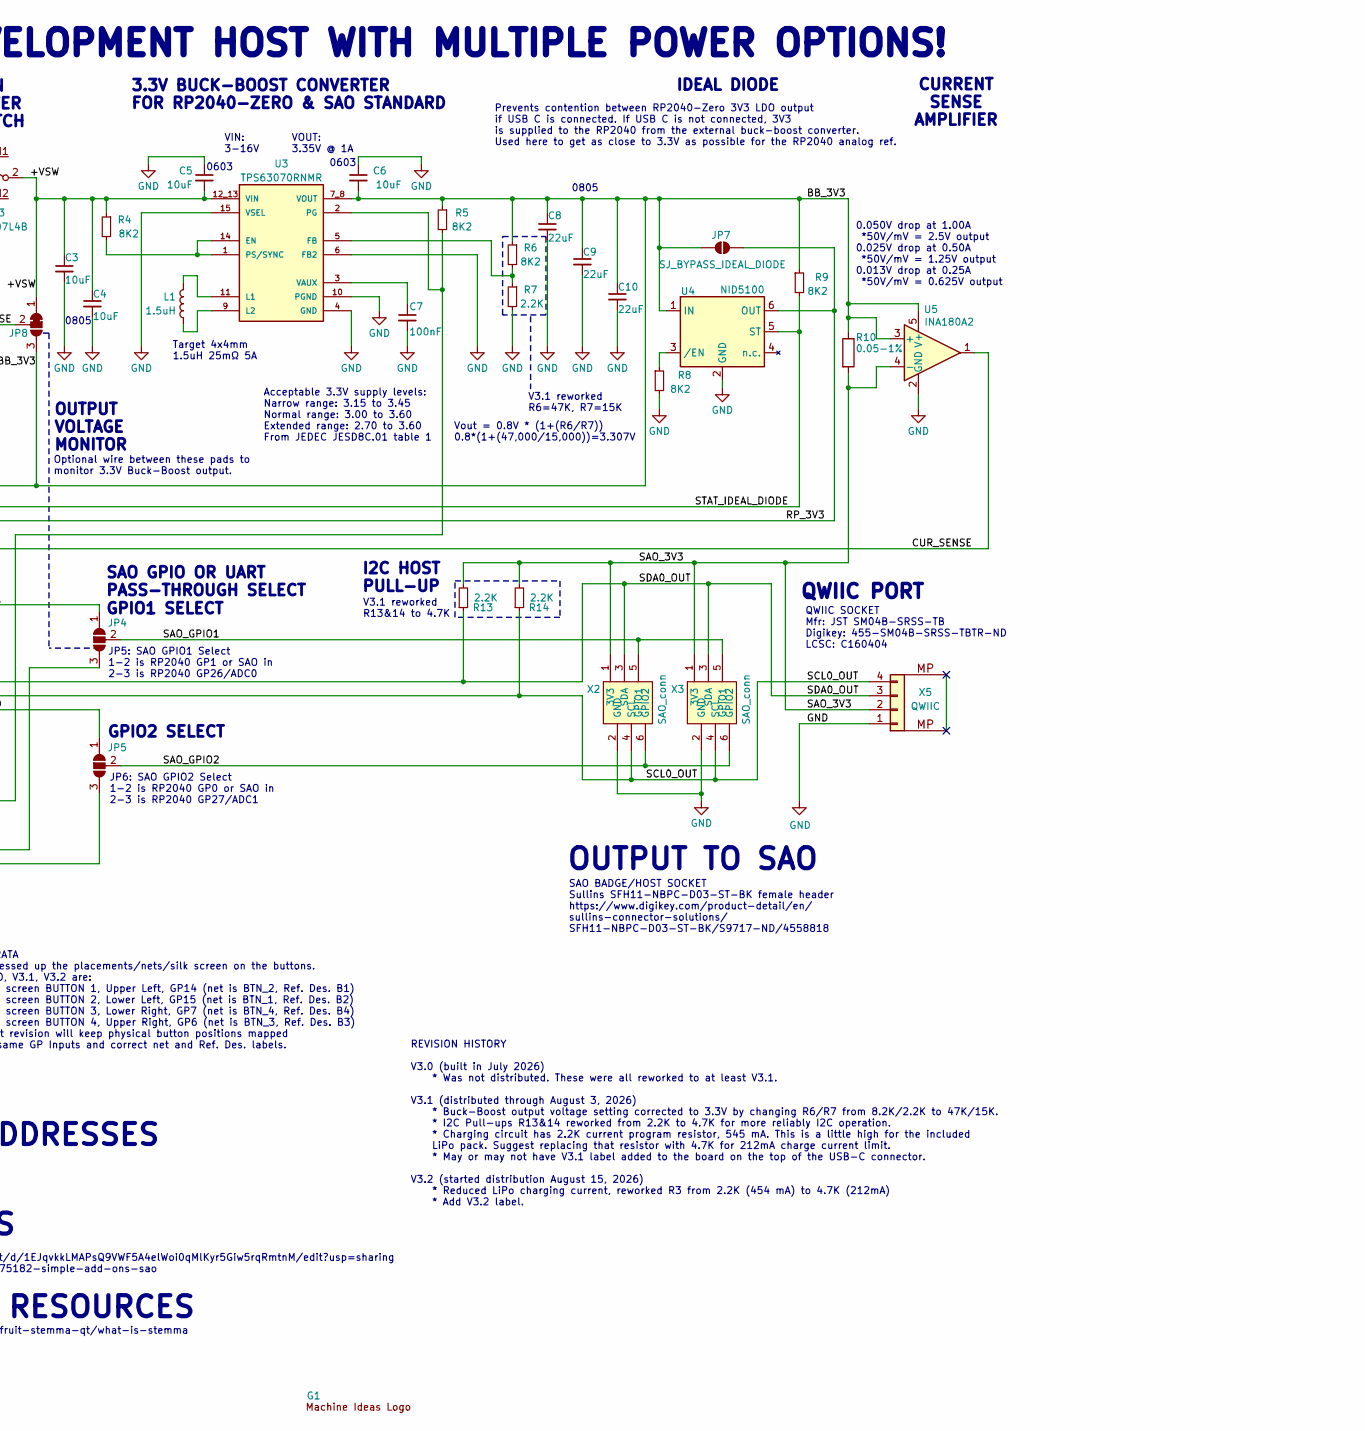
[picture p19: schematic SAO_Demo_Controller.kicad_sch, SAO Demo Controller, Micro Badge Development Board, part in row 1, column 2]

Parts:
B1, B2, B3, B4: EVQP7J01P; SMD4_SW_EVQP7J_PAN; LCSC C2828254
C1, C7: 100nF; C_0603_1608Metric; LCSC C14663
C2, C6: 10uF; C_0603_1608Metric; LCSC C19702
C3, C4, C11: 10uF; C_0805_2012Metric; LCSC C15850
C5: 10uF; C_0603_1608Metric; LCSC C96446
C8, C9, C10: 22uF; C_0805_2012Metric; LCSC C45783
D1, D2, D3, D4: SD0805S020S1R0; D_0805_2012Metric; LCSC C143773
D5: LED; LED_0603_1608Metric; LCSC C2286
G1: Machine_Ideas_logo
J1: BATT.; PinSocket_1x02_P2.54mm_Vertical
J2: BATT.; JST_PH_S2B-PH-SM4-TB_1x02-1MP_P2.00mm_Horizontal; LCSC C295747
JP2: SJ_GPIO1_PASSTHRU; SolderJumper-2_P1.3mm_Open_RoundedPad1.0x1.5mm
JP3: SJ_GPIO2_PASSTHRU; SolderJumper-2_P1.3mm_Open_RoundedPad1.0x1.5mm
JP4, JP5: SolderJumper_3_Open; SolderJumper-3_P1.3mm_Open_RoundedPad1.0x1.5mm_NumberLabels
JP6: SJ_REV_PWR_BDG; SolderJumper-2_P1.3mm_Open_RoundedPad1.0x1.5mm
JP7: SJ_BYPASS_IDEAL_DIODE; SolderJumper-2_P1.3mm_Open_RoundedPad1.0x1.5mm
JP8: SolderJumper_3_Open; SolderJumper-3_P1.3mm_Bridged12_RoundedPad1.0x1.5mm
L1: 1.5uH; L_Sunlord_SWPA4020S; LCSC C98360
R1, R2: 1K; R_0603_1608Metric; LCSC C21190
R3, R7, R13, R14: 2.2K; R_0603_1608Metric; LCSC C4190
R4, R5, R6, R8, R9: 8K2; R_0603_1608Metric; LCSC C25981
R10: 0.05-1%; R_0805_2012Metric; LCSC C5141277
R11: 8K2; R_0603_1608Metric; Manufacturer_Part_Number RK73H2ATTD3301F; LCSC C25981
R12: 2.2K; R_0603_1608Metric; Manufacturer_Part_Number RK73H2ATTD3301F; LCSC C4190
SW3: SK12D07L4B; Switch_SK12D07VG4; LCSC C480340
U1: RY2201; SOT-23-5_HandSoldering; LCSC C370889
U2: TP4054; SOT-23-5; LCSC C382138
U3: TPS63070RNMR; VREG_TPS63070RNMR; PARTREV B; LCSC C109322
U4: NID5100; SOT-363_SC-70-6; LCSC C40065155
U5: INA180A2; SOT-23-5; LCSC C192764
U6: RP2040-Zero; RP2040 Zero
X1: SAO_conn; Badgelife-SAOv169-BADGE-2x3-no-front-text; MPN SFH11-NBPC-D03-ST-BK
X2, X3: SAO_conn; Badgelife-SAOv169-BADGE-2x3-no-front-text-yes-front-outline; MPN SFH11-NBPC-D03-ST-BK
X5: QWIIC; JST_SH_SM04B-SRSS-TB_1x04-1MP_P1.00mm_Horizontal; MPN SM04B-SRSS-TB; LCSC C160404

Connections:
/+BATT: D2.2 (A), J1.1
/+LIPO: D3.2 (A), J2.1, R1.2, U2.3 (BAT)
/+VSW: C3.1, C4.1, C5.2, JP8.1 (A), R4.1, SW3.2 (B), U3.12_13 (VIN)
/-LIPO: C1.2, J2.2, U1.2 (BAT-)
/BB_3V3: C6.2, C8.1, C9.1, C10.1, JP6.2 (B), JP7.1 (A), JP8.3 (B), R5.1, R6.1, R9.1, R10.1, U3.7_8 (VOUT), U4.1 (IN), U5.3 (+), U5.5 (V+)
/BRX_SAOTX: JP3.1 (A), X1.6 (GPIO2)
/BTN_1: B2.1, U6.15 (GP15)
/BTN_2: B1.1, U6.14 (GP14)
/BTN_3: B3.1, U6.6 (GP6)
/BTN_4: B4.1, U6.7 (GP7)
/BTX_SAORX: JP2.1 (A), X1.5 (GPIO1)
/CUR_SENSE: U5.1, U6.28 (GP28/ADC2)
/GP0: JP3.2 (B), JP5.1 (A), U6.0 (SDA0/GP0)
/GP1: JP2.2 (B), JP4.1 (A), U6.1 (SCL0/GP1)
/PG: R5.2, U3.2 (PG), U6.9 (GP9)
/RP_3V3: C11.1, JP7.2 (B), U4.6 (OUT), U6.33 (3V3)
/SAO_3V3: R10.2, R13.2, R14.2, U5.4 (-), X2.1 (3V3), X3.1 (3V3), X5.2
/SAO_GPIO1: JP4.2 (C), X2.5 (GPIO1), X3.5 (GPIO1)
/SAO_GPIO1_GP26: JP4.3 (B), U6.26 (GP26/ADC0)
/SAO_GPIO2: JP5.2 (C), X2.6 (GPIO2), X3.6 (GPIO2)
/SAO_GPIO2_GP27: JP5.3 (B), U6.27 (GP27/ADC1)
/SCL0_OUT: R14.1, U6.5 (GP5), X2.4 (SCL), X3.4 (SCL), X5.4
/SCL1_IN: U6.3 (GP3), X1.4 (SCL)
/SDA0_OUT: R13.1, U6.4 (GP4), X2.3 (SDA), X3.3 (SDA), X5.3
/SDA1_IN: U6.2 (SDA1/GP2), X1.3 (SDA)
/STAT_IDEAL_DIODE: R9.2, U4.5 (ST), U6.8 (GP8)
/VIN_BDG: D4.2 (A), JP6.1 (A), X1.1 (3V3)
/VIN_SENSE_DIV: R11.2, R12.1, U6.29 (GP29/ADC3)
/VIN_USB: C2.1, D1.2 (A), R2.1, U2.4 (V_{CC}), U6.35 (5V/VUSB)
/V_IN: D1.1 (K), D2.1 (K), D3.1 (K), D4.1 (K), SW3.1 (A)
/V_SENSE: JP8.2 (C), R11.1
GND: B1.2, B2.2, B3.2, B4.2, C2.2, C3.2, C4.2, C5.1, C6.1, C7.2, C8.2, C9.2, C10.2, C11.2, J1.2, R3.2, R7.2, R8.2, R12.2, U1.4 (GND), U1.5 (GND), U2.2 (GND), U3.4 (GND), U3.6 (FB2), U3.10 (PGND), U3.15 (VSEL), U4.2 (GND), U5.2 (GND), U6.34 (GND), X1.2 (GND), X2.2 (GND), X3.2 (GND), X5.1
unnamed: D5.2 (A), R2.2
unnamed: D5.1 (K), U2.1 (~CHRG)
unnamed: C1.1, R1.1, U1.3 (BAT+)
unnamed: R3.1, U2.5 (PROG)
unnamed: R4.2, U3.1 (PS/SYNC), U3.14 (EN)
unnamed: R6.2, R7.1, U3.5 (FB)
unnamed: L1.1, U3.11 (L1)
unnamed: L1.2, U3.9 (L2)
unnamed: C7.1, U3.3 (VAUX)
unnamed: R8.1, U4.3 (/EN)

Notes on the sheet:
5V USB
POWER REV. POLARITY & BACKFEED PROTECTION
SAO GPIO OR UART PASS-THROUGH SELECT
DEMO CONTROLLER FUNCTIONS: INPUT 3-5V from Badge or USB-C GROUND 3V3 @ ~200mA regulated from ZERO VIN/2 input voltage measurement SAO output current measurement SAO GPIO2 SAO GPIO1 USER BUTTON 2 USER BUTTON 1
Battery charging current is 1000/R3 2.0K : 500mA (max, V3.0 & V3.1) 4.7K : 212mA (V3.2) 10K : 100mA
See Ideal Diode note.
SAO BADGE/HOST SOCKET Sullins SFH11-NBPC-D03-ST-BK female header https://www.digikey.com/product-detail/en/ sullins-connector-solutions/ SFH11-NBPC-D03-ST-BK/S9717-ND/4558818
For 1S LiPo or Li-Ion cells only.
USER BUTTON 2
COMMON I2C ADDRESSES
QWIIC SOCKET Mfr: JST SM04B-SRSS-TB Digikey: 455-SM04B-SRSS-TBTR-ND LCSC: C160404
MAIN POWER SWITCH
USER BUTTON 1
0805
RP2040-Zero See https://www.waveshare.com/wiki/RP2040-Zero for more information and more GPIO on bottom pads. Onboard buttons not user accessible. GPIO16 is NeoPixel onboard.
USER: SPI, SD CARD, I2C, UART
V3.1 reworked R6=47K, R7=15K
GPIO1 SELECT
https://learn.adafruit.com/introducing-adafruit-stemma-qt/what-is-stemma
Acceptable 3.3V supply levels: Narrow range: 3.15 to 3.45 Normal range: 3.00 to 3.60 Extended range: 2.70 to 3.60 From JEDEC JESD8C.01 table 1
USER BUTTON 4
DEMO CONTROLLER FUNCTIONS: SAO GPIO2 pass-through or Badge RX / SAO TX SAO GPIO1 pass-through or Badge TX / SAO RX SDA1 IN from Badge SCL1 IN from Badge SDA0 OUT to SAO SCL0 OUT to SAO USER BUTTON 3 USER BUTTON 4 USER 5100 STATUS/UART USER GPIO/I2C/UART USER SPI_CLK/I2C1_SDA/UART USER SPI_TX_OUT/I2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
ERRATA I messed up the placements/nets/silk screen on the buttons. V3.0, V3.1, V3.2 are: Silk screen BUTTON 1, Upper Left, GP14 (net is BTN_2, Ref. Des. B1) Silk screen BUTTON 2, Lower Left, GP15 (net is BTN_1, Ref. Des. B2) Silk screen BUTTON 3, Lower Right, GP7 (net is BTN_4, Ref. Des. B4) Silk s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
0603
0.050V drop at 1.00A *50V/mV = 2.5V output 0.025V drop at 0.50A *50V/mV = 1.25V output 0.013V drop at 0.25A *50V/mV = 0.625V output
SAO CLIENT PLUG https://www.digikey.com/en/products/ detail/adam-tech/BHR-06-VUA/10414837 GPIO1 is also data from the badge to the SAO (Badge TX, SAO RX). GPIO2 is also data from the SAO to the badge (Badge RX, SAO TX).
3.3V NOM.
OLED (SSD1306) 128x32 0x3C OLED (SSD1306) 128x64 0x3D OLED (SSD1327) 128x128 0x3C
FROM HOST BADGE
V3.1 reworked R13&14 to 4.7K
Alkaline (header 0.1in/2.54mm)
BAT+ 6V MAX
QWIIC/STEMMA RESOURCES
IDEAL DIODE
RED/ON= Charging
SAO STANDARDS
See Power Sources note 3B.
Adafruit LiPo JST PH 2mm
I2C HOST PULL-UP
LIPO PROTECTOR

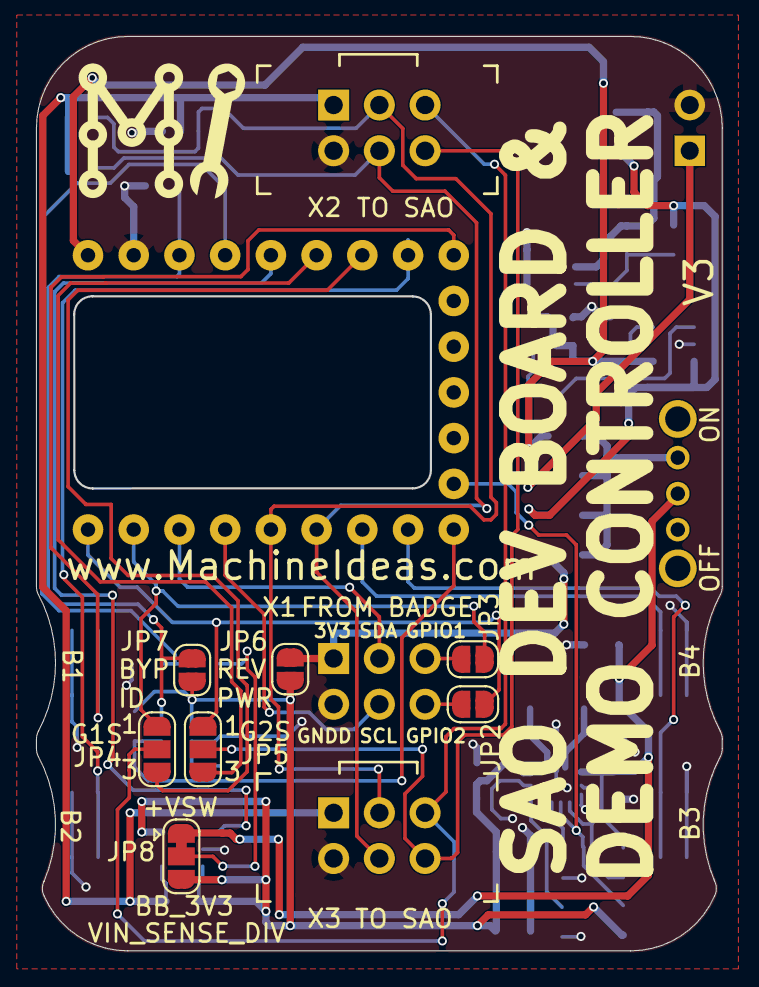
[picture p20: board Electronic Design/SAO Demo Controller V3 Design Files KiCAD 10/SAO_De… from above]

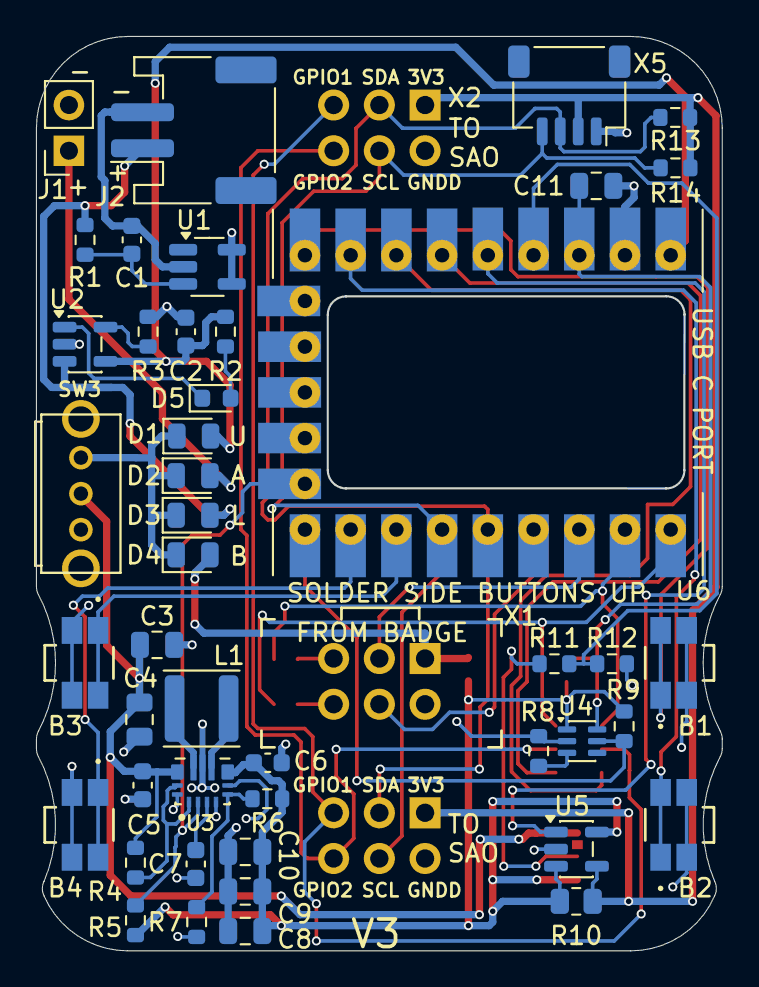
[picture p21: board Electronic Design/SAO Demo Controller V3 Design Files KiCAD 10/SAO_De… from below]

Board: 2 copper layers, 38.1 x 50.8 mm, 56 parts (45 on the bottom side), 42 nets.

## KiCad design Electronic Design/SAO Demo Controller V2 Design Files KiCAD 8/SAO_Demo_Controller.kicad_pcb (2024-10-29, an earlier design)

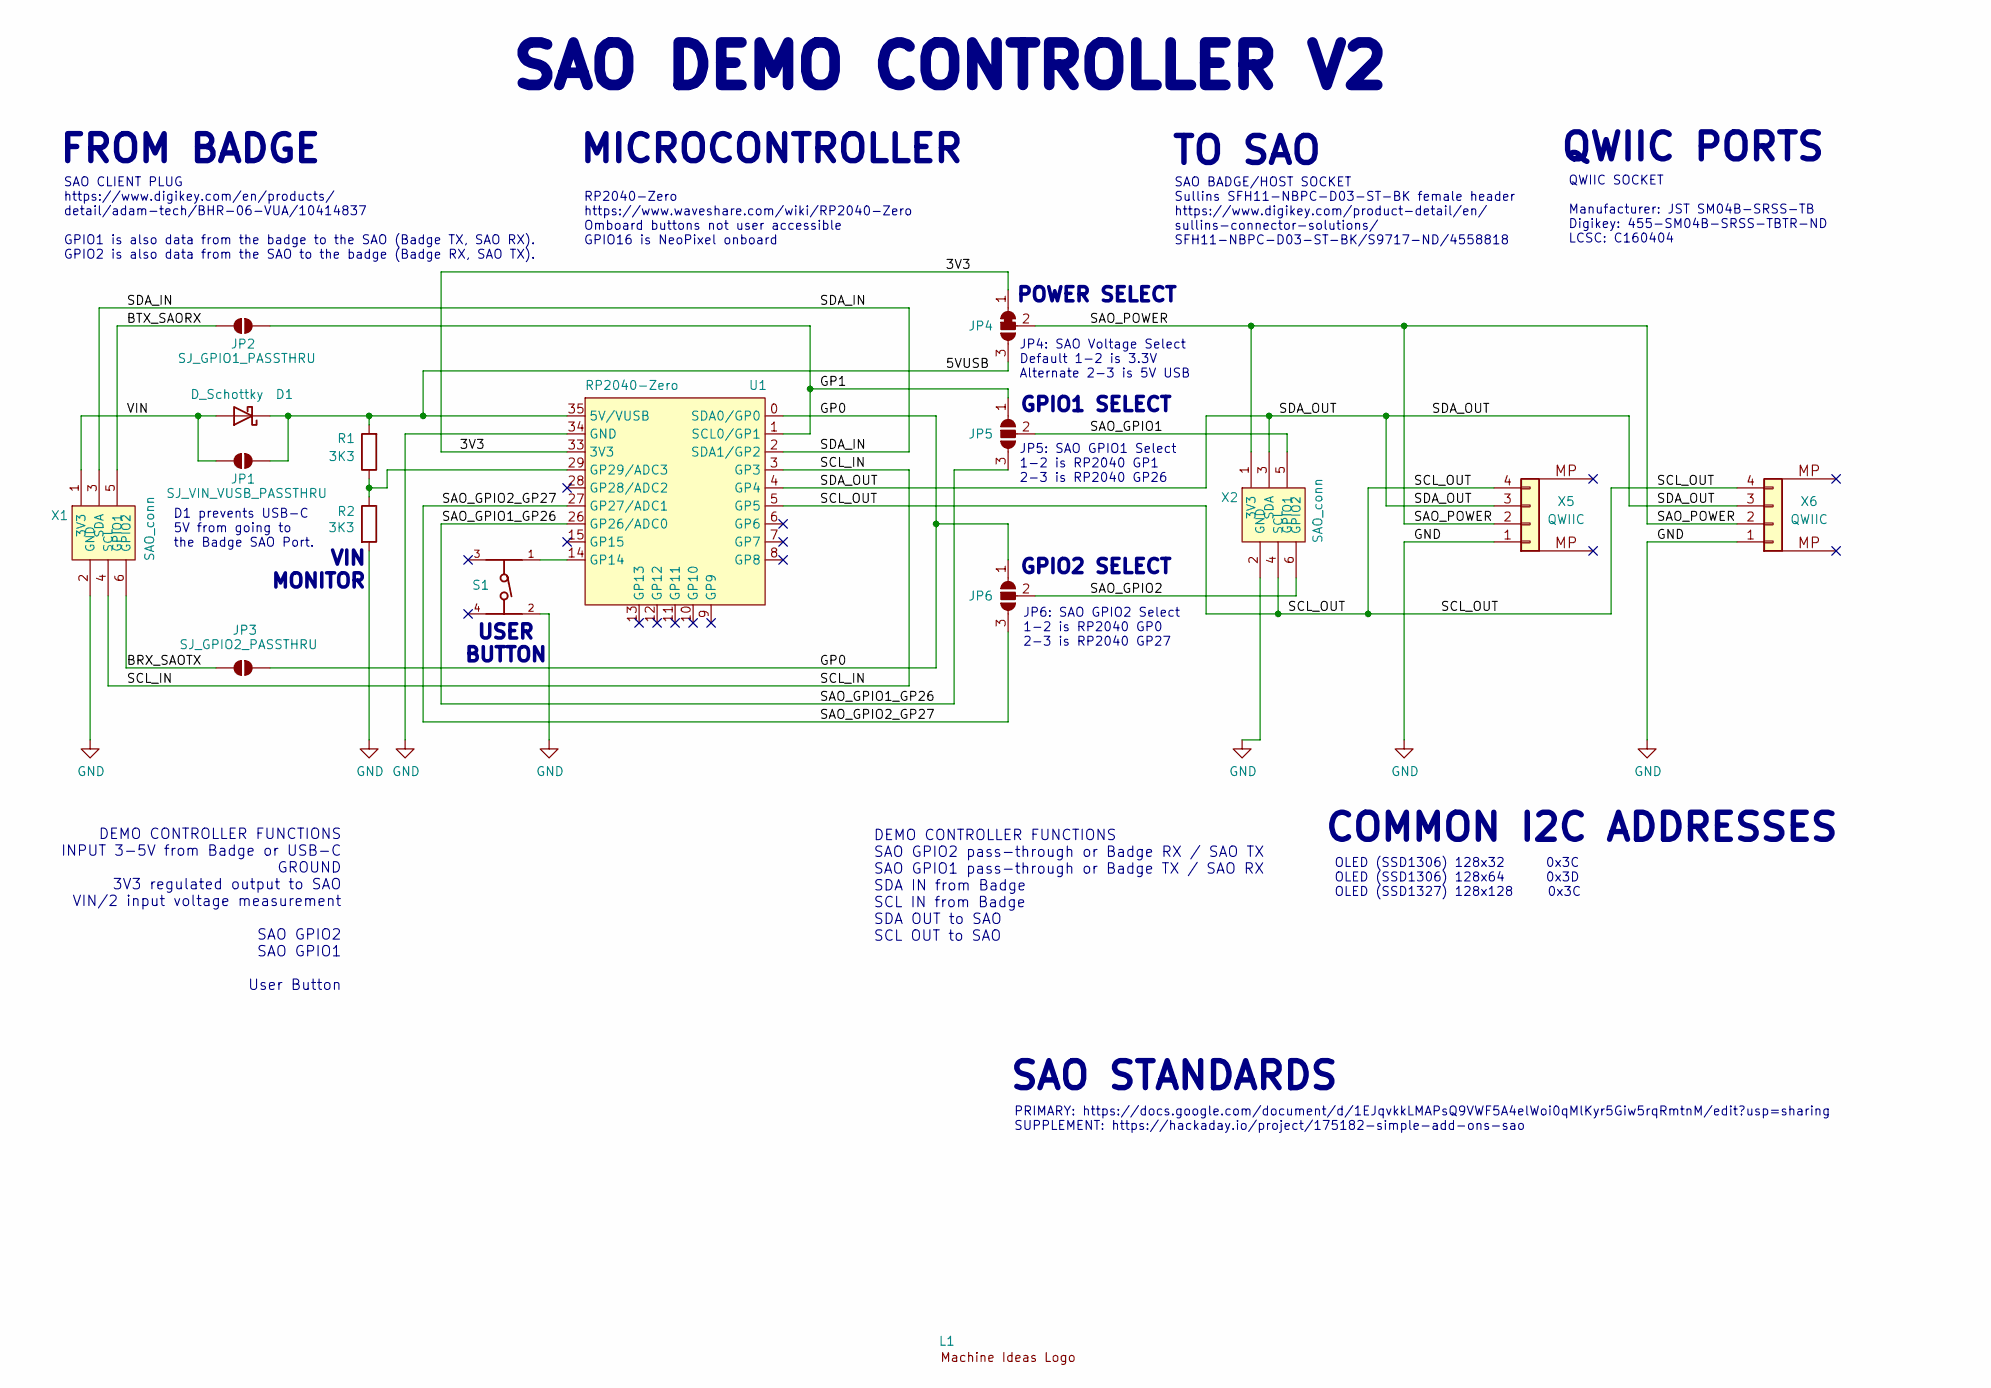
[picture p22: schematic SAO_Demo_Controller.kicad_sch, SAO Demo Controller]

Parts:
D1: D_Schottky; D_0805_2012Metric
JP1: SJ_VIN_VUSB_PASSTHRU; SolderJumper-2_P1.3mm_Open_RoundedPad1.0x1.5mm
JP2: SJ_GPIO1_PASSTHRU; SolderJumper-2_P1.3mm_Open_RoundedPad1.0x1.5mm
JP3: SJ_GPIO2_PASSTHRU; SolderJumper-2_P1.3mm_Open_RoundedPad1.0x1.5mm
JP4: SolderJumper_3_Open; SolderJumper-3_P1.3mm_Bridged12_RoundedPad1.0x1.5mm_NumberL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
JP5, JP6: SolderJumper_3_Open; SolderJumper-3_P1.3mm_Open_RoundedPad1.0x1.5mm_NumberLabels
L1: Machine_Ideas_logo
R1, R2: 3K3; R_0805_2012Metric; Manufacturer_Part_Number RK73H2ATTD3301F
S1: 434331045822; Button_Wurth_4343X10458XX; PART-NUMBER 434331045822
U1: RP2040-Zero; RP2040 Zero
X1: SAO_conn; Badgelife-SAOv169-BADGE-2x3-Edge-Connect-no-front-text; MPN SFH11-NBPC-D03-ST-BK
X2: SAO_conn; Badgelife-SAOv169-BADGE-2x3-no-front-text; MPN SFH11-NBPC-D03-ST-BK
X5, X6: QWIIC; JST_SH_SM04B-SRSS-TB_1x04-1MP_P1.00mm_Horizontal; MPN SM04B-SRSS-TB; LCSC C160404

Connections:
/3V3: JP4.1 (A), U1.33 (3V3)
/5VUSB: D1.1 (K), JP1.2 (B), JP4.3 (B), R1.2, U1.35 (5V/VUSB)
/BRX_SAOTX: JP3.1 (A), X1.6 (GPIO2)
/BTX_SAORX: JP2.1 (A), X1.5 (GPIO1)
/GP0: JP3.2 (B), JP6.1 (A), U1.0 (SDA0/GP0)
/GP1: JP2.2 (B), JP5.1 (A), U1.1 (SCL0/GP1)
/SAO_GPIO1: JP5.2 (C), X2.5 (GPIO1)
/SAO_GPIO1_GP26: JP5.3 (B), U1.26 (GP26/ADC0)
/SAO_GPIO2: JP6.2 (C), X2.6 (GPIO2)
/SAO_GPIO2_GP27: JP6.3 (B), U1.27 (GP27/ADC1)
/SAO_POWER: JP4.2 (C), X2.1 (3V3), X5.2, X6.2
/SCL_IN: U1.3 (GP3), X1.4 (SCL)
/SCL_OUT: U1.5 (GP5), X2.4 (SCL), X5.4, X6.4
/SDA_IN: U1.2 (SDA1/GP2), X1.3 (SDA)
/SDA_OUT: U1.4 (GP4), X2.3 (SDA), X5.3, X6.3
/VIN: D1.2 (A), JP1.1 (A), X1.1 (3V3)
GND: R2.2, S1.2, U1.34 (GND), X1.2 (GND), X2.2 (GND), X5.1, X6.1
unnamed: S1.1, U1.14 (GP14)
unnamed: R1.1, R2.1, U1.29 (GP29/ADC3)

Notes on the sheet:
DEMO CONTROLLER FUNCTIONS INPUT 3-5V from Badge or USB-C GROUND 3V3 regulated output to SAO VIN/2 input voltage measurement SAO GPIO2 SAO GPIO1 User Button
POWER SELECT
SAO BADGE/HOST SOCKET Sullins SFH11-NBPC-D03-ST-BK female header https://www.digikey.com/product-detail/en/ sullins-connector-solutions/ SFH11-NBPC-D03-ST-BK/S9717-ND/4558818
COMMON I2C ADDRESSES
QWIIC SOCKET Manufacturer: JST SM04B-SRSS-TB Digikey: 455-SM04B-SRSS-TBTR-ND LCSC: C160404
USER BUTTON
RP2040-Zero https://www.waveshare.com/wiki/RP2040-Zero Omboard buttons not user accessible GPIO16 is NeoPixel onboard
GPIO1 SELECT
DEMO CONTROLLER FUNCTIONS SAO GPIO2 pass-through or Badge RX / SAO TX SAO GPIO1 pass-through or Badge TX / SAO RX SDA IN from Badge SCL IN from Badge SDA OUT to SAO SCL OUT to SAO
SAO CLIENT PLUG https://www.digikey.com/en/products/ detail/adam-tech/BHR-06-VUA/10414837 GPIO1 is also data from the badge to the SAO (Badge TX, SAO RX). GPIO2 is also data from the SAO to the badge (Badge RX, SAO TX).
OLED (SSD1306) 128x32 0x3C OLED (SSD1306) 128x64 0x3D OLED (SSD1327) 128x128 0x3C
FROM BADGE
SAO STANDARDS
JP4: SAO Voltage Select Default 1-2 is 3.3V Alternate 2-3 is 5V USB
PRIMARY: https://docs.google.com/document/d/1EJqvkkLMAPsQ9VWF5A4elWoi0qMlKyr5Giw5rqRmtnM/edit?usp=sharing SUPPLEMENT: https://hackaday.io/project/175182-simple-add-ons-sao
VIN MONITOR
QWIIC PORTS
JP5: SAO GPIO1 Select 1-2 is RP2040 GP1 2-3 is RP2040 GP26
TO SAO
D1 prevents USB-C 5V from going to the Badge SAO Port.
JP6: SAO GPIO2 Select 1-2 is RP2040 GP0 2-3 is RP2040 GP27
SAO DEMO CONTROLLER V2
GPIO2 SELECT
MICROCONTROLLER

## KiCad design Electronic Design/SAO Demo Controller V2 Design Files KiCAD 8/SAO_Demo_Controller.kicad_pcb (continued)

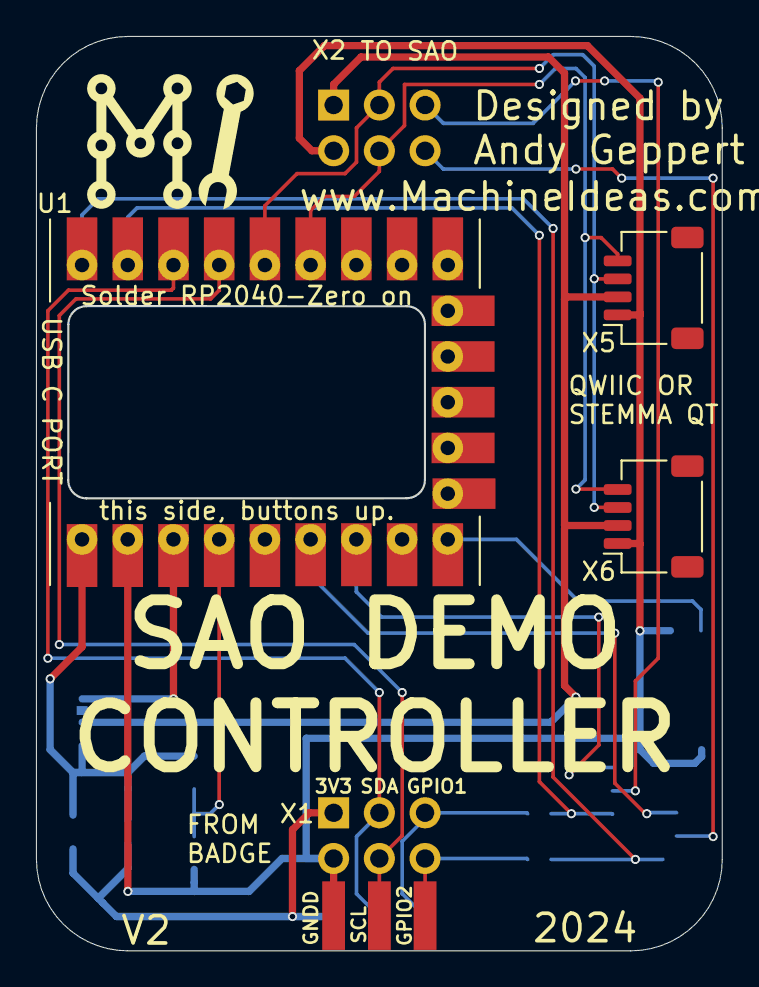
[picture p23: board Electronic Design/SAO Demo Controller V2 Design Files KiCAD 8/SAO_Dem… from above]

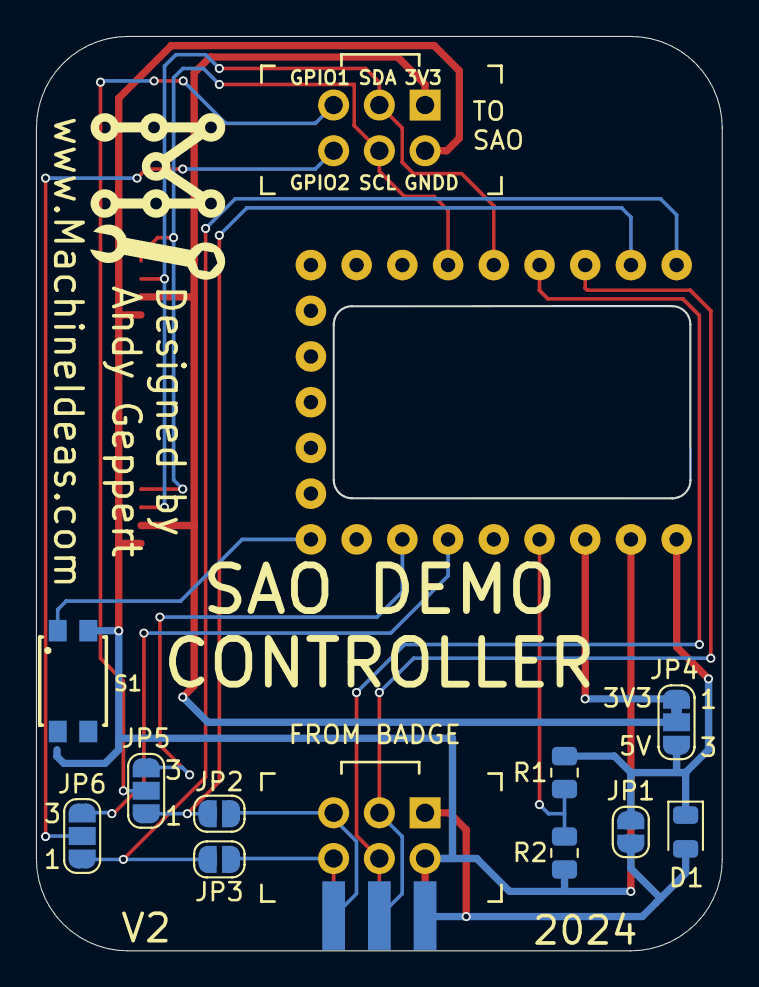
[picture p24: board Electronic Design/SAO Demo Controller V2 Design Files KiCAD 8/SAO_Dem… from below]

Board: 2 copper layers, 38.1 x 50.8 mm, 17 parts (11 on the bottom side), 19 nets.

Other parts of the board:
L1#2: Machine_Ideas_logo

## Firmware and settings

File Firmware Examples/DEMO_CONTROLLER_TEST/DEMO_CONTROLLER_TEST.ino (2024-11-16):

// SAO DEMO CONTROLLER TEST
// Andy Geppert, firmware version 2024-11-16
// Compatible with SAO Demo Controller V1 and V2
// https://hackaday.io/project/198034-sao-demo-controller
// Using RP2040-Zero (select Raspberry Pi Pico in Arduino IDE)
// Testing for: Built-in Zero RGB LED, SSD1306 128x32 or 128x64 OLED modules, button, voltage reading

// Built on:
  /**************************************************************************
  This is an example for our Monochrome OLEDs based on SSD1306 drivers

  Pick one up today in the adafruit shop!
  ------> http://www.adafruit.com/category/63_98

  This example is for a 128x32 pixel display using I2C to communicate
  3 pins are required to interface (two I2C and one reset).

  Adafruit invests time and resources providing this open
  source code, please support Adafruit and open-source
  hardware by purchasing products from Adafruit!

  Written by Limor Fried/Ladyada for Adafruit Industries,
  with contributions from the open source community.
  BSD license, check license.txt for more information
  All text above, and the splash screen below must be
  included in any redistribution.
  **************************************************************************/

// -------------------------------------------------------------------------------------------------------------------
//                                              CHOOSE YOUR OPTIONS!
// -------------------------------------------------------------------------------------------------------------------

// Chose one OLED option
  #define OLED_SSD1306_128x32     // This works to test the 128x32 and 128x64 (kinda) OLED screens.
  // #define OLED_SSD1306_128x64  // TODO: As of 2024-11-6 Adafruit_SSD1306 V2.5.13 does not work in this mode.
// Choose any of these optios:
  #define BUILT_IN_RGB_LED
  #define VOLTAGE_DISPLAY
  // #define ADAFRUIT_GRAPHICS_DEMO // TODO: Implement this #define check in LOOP()
  #define BUTTON_TEST               // TODO: Implement this cycle RGB LED
// -------------------------------------------------------------------------------------------------------------------
// -------------------------------------------------------------------------------------------------------------------

#include <SPI.h>
#include <Wire.h>
#include <Adafruit_GFX.h>     // V1.11.11
#include <Adafruit_SSD1306.h> // V2.5.13

#if defined OLED_SSD1306_128x32
  #define SCREEN_WIDTH 128 // OLED display width, in pixels
  #define SCREEN_HEIGHT 32 // OLED display height, in pixels
#elif defined OLED_SSD1306_128x64
  #define SCREEN_WIDTH 128 // OLED display width, in pixels
  #define SCREEN_HEIGHT 64 // OLED display height, in pixels
#else
  #error ("Hardware version undefined or unsupported.")
#endif

#if defined BUILT_IN_RGB_LED
  // NeoPixel Ring simple sketch (c) 2013 Shae Erisson
  // Released under the GPLv3 license to match the rest of the
  // Adafruit NeoPixel library
  #include <Adafruit_NeoPixel.h>
  #ifdef __AVR__
  #include <avr/power.h> // Required for 16 MHz Adafruit Trinket
  #endif
  // Which pin on the Arduino is connected to the NeoPixels?
  #define PIN        16 // On Trinket or Gemma, suggest changing this to 1

  // How many NeoPixels are attached to the Arduino?
  #define NUMPIXELS 1 // Popular NeoPixel ring size

  // When setting up the NeoPixel library, we tell it how many pixels,
  // and which pin to use to send signals. Note that for older NeoPixel
  // strips you might need to change the third parameter -- see the
  // strandtest example for more information on possible values.
  Adafruit_NeoPixel pixels(NUMPIXELS, PIN, NEO_RGB + NEO_KHZ800);

  // Appears to be a TM1804 RGB order LED ^^^^^^^^^ used for the SAO Demo Controller boards
  #define DELAYVAL 100 // Time (in milliseconds) to pause between pixels
#endif 

#if defined VOLTAGE_DISPLAY
  uint8_t  voltagePin = A3;                  // select the input pin for the potentiometer
  uint16_t sensorValue = 0;                  // variable to store the value coming from the sensor
  float    sensorScalarVperCount = 0.006452; // 3.3V / 1023 counts * 2:1 voltage divider scalar
#endif

// Declaration for an SSD1306 display connected to I2C (SDA, SCL pins)
// The pins for I2C are defined by the Wire-library. 
// On an arduino UNO:       A4(SDA), A5(SCL)
// On an arduino MEGA 2560: 20(SDA), 21(SCL)
// On an arduino LEONARDO:   2(SDA),  3(SCL), ...
#define OLED_RESET     -1 // Reset pin # (or -1 if sharing Arduino reset pin)
#define SCREEN_ADDRESS 0x3C ///< See datasheet for Address; 0x3D for 128x64, 0x3C for 128x32
Adafruit_SSD1306 display(SCREEN_WIDTH, SCREEN_HEIGHT, &Wire, OLED_RESET, 1000000);

#define NUMFLAKES     10 // Number of snowflakes in the animation example

#define LOGO_HEIGHT   16
#define LOGO_WIDTH    16
static const unsigned char PROGMEM logo_bmp[] =
{ 0b00000000, 0b11000000,
  0b00000001, 0b11000000,
  0b00000001, 0b11000000,
  0b00000011, 0b11100000,
  0b11110011, 0b11100000,
  0b11111110, 0b11111000,
  0b01111110, 0b11111111,
  0b00110011, 0b10011111,
  0b00011111, 0b11111100,
  0b00001101, 0b01110000,
  0b00011011, 0b10100000,
  0b00111111, 0b11100000,
  0b00111111, 0b11110000,
  0b01111100, 0b11110000,
  0b01110000, 0b01110000,
  0b00000000, 0b00110000 };

void blinkRGBLEDred() {
  #if defined BUILT_IN_RGB_LED
    // The first NeoPixel in a strand is #0, second is 1, all the way up
    // to the count of pixels minus one.
    for(int i=0; i<NUMPIXELS; i++) { // For each pixel...
      // pixels.Color() takes RGB values, from 0,0,0 up to 255,255,255
      // Here we're using a moderately bright green color:
      pixels.setPixelColor(i, pixels.Color(0, 25, 0));
      pixels.show();   // Send the updated pixel colors to the hardware.
      delay(DELAYVAL); // Pause before next pass through loop
      pixels.clear(); // Set all pixel colors to 'off'
      pixels.show();   // Send the updated pixel colors to the hardware.
    }
  #endif
}

void blinkRGBLEDgreen() {
  #if defined BUILT_IN_RGB_LED
    // The first NeoPixel in a strand is #0, second is 1, all the way up
    // to the count of pixels minus one.
    for(int i=0; i<NUMPIXELS; i++) { // For each pixel...
      // pixels.Color() takes RGB values, from 0,0,0 up to 255,255,255
      // Here we're using a moderately bright green color:
      pixels.setPixelColor(i, pixels.Color(25, 0, 0));
      pixels.show();   // Send the updated pixel colors to the hardware.
      delay(DELAYVAL); // Pause before next pass through loop
      pixels.clear(); // Set all pixel colors to 'off'
      pixels.show();   // Send the updated pixel colors to the hardware.
    }
  #endif
}

void blinkRGBLEDblue() {
  #if defined BUILT_IN_RGB_LED
    // The first NeoPixel in a strand is #0, second is 1, all the way up
    // to the count of pixels minus one.
    for(int i=0; i<NUMPIXELS; i++) { // For each pixel...
      // pixels.Color() takes RGB values, from 0,0,0 up to 255,255,255
      // Here we're using a moderately bright green color:
      pixels.setPixelColor(i, pixels.Color(0, 0, 25));
      pixels.show();   // Send the updated pixel colors to the hardware.
      delay(DELAYVAL); // Pause before next pass through loop
      pixels.clear(); // Set all pixel colors to 'off'
      pixels.show();   // Send the updated pixel colors to the hardware.
    }
  #endif
}

void AnalogVoltageReadDisplay() {
  #if defined VOLTAGE_DISPLAY
    for(int i=0; i<30; i++) {
      sensorValue = analogRead(voltagePin);
      Serial.print("VIN: ");
      Serial.println(sensorValue * sensorScalarVperCount);
      // OLED Update
      display.clearDisplay();
      display.setTextSize(2);
      display.setTextColor(SSD1306_WHITE); // Draw white text
      display.setCursor(0, 0);     // Start at top-left corner
      display.cp437(true);         // Use full 256 char 'Code Page 437' font
      display.print("VIN: ");
      display.println(sensorValue * sensorScalarVperCount);
      display.display();
      delay(100);
    }
  #endif
}

void setup() {
  Serial.begin(115200);
  delay (3000);

  #if defined BUILT_IN_RGB_LED
    // These lines are specifically to support the Adafruit Trinket 5V 16 MHz.
    // Any other board, you can remove this part (but no harm leaving it):
    #if defined(__AVR_ATtiny85__) && (F_CPU == 16000000)
      clock_prescale_set(clock_div_1);
    #endif
    // END of Trinket-specific code.
    pixels.begin(); // INITIALIZE NeoPixel strip object (REQUIRED)
    Serial.println(F("Blink the RP2040-Zero built-in RGB LED."));
  #endif

  Serial.println(F("Hello World 1306"));
  // SSD1306_SWITCHCAPVCC = generate display voltage from 3.3V internally
  display.begin(SCREEN_ADDRESS);
  if(!display.begin(SSD1306_SWITCHCAPVCC, SCREEN_ADDRESS)) {
    Serial.println(F("SSD1306 allocation failed"));
//    for(;;); // Don't proceed, loop forever
  }
  #if defined VOLTAGE_DISPLAY
    /// Nothing needed since default start-up is analog reading
  #endif
  AnalogVoltageReadDisplay();
}

void loop() {
  AnalogVoltageReadDisplay();

  Serial.println(F("Display begin"));
  // Show initial display buffer contents on the screen --
  // the library initializes this with an Adafruit splash screen.
  display.display();
  delay(1000); // Pause for 2 seconds
  blinkRGBLEDred();

  // Clear the buffer
  display.clearDisplay();

  // Draw a single pixel in white
  display.drawPixel(10, 10, SSD1306_WHITE);

  // Show the display buffer on the screen. You MUST call display() after
  // drawing commands to make them visible on screen!
  display.display();
  delay(1000);
  blinkRGBLEDgreen();
  // display.display() is NOT necessary after every single drawing command,
  // unless that's what you want...rather, you can batch up a bunch of
  // drawing operations and then update the screen all at once by calling
  // display.display(). These examples demonstrate both approaches...

  testdrawline();      // Draw many lines
  blinkRGBLEDblue();

  testdrawrect();      // Draw rectangles (outlines)
  blinkRGBLEDred();

  testfillrect();      // Draw rectangles (filled)
  blinkRGBLEDgreen();

  testdrawcircle();    // Draw circles (outlines)
  blinkRGBLEDblue();

  testfillcircle();    // Draw circles (filled)
  blinkRGBLEDred();

  testdrawroundrect(); // Draw rounded rectangles (outlines)
  blinkRGBLEDgreen();

  testfillroundrect(); // Draw rounded rectangles (filled)
  blinkRGBLEDblue();

  testdrawtriangle();  // Draw triangles (outlines)
  blinkRGBLEDred();

  testfilltriangle();  // Draw triangles (filled)
  blinkRGBLEDgreen();

  testdrawchar();      // Draw characters of the default font
  blinkRGBLEDblue();

  testdrawstyles();    // Draw 'stylized' characters
  blinkRGBLEDred();

  testscrolltext();    // Draw scrolling text
  blinkRGBLEDgreen();

  testdrawbitmap();    // Draw a small bitmap image
  blinkRGBLEDblue();

  // Invert and restore display, pausing in-between
  display.invertDisplay(true);
  delay(1000);
  blinkRGBLEDred();
  display.invertDisplay(false);
  delay(1000);
  blinkRGBLEDgreen();

  // estanimate(logo_bmp, LOGO_WIDTH, LOGO_HEIGHT); // Animate bitmaps
  blinkRGBLEDblue();
}

void testdrawline() {
  int16_t i;

  display.clearDisplay(); // Clear display buffer

  for(i=0; i<display.width(); i+=4) {
    display.drawLine(0, 0, i, display.height()-1, SSD1306_WHITE);
    display.display(); // Update screen with each newly-drawn line
    delay(1);
  }
  for(i=0; i<display.height(); i+=4) {
    display.drawLine(0, 0, display.width()-1, i, SSD1306_WHITE);
    display.display();
    delay(1);
  }
  delay(250);

  display.clearDisplay();

  for(i=0; i<display.width(); i+=4) {
    display.drawLine(0, display.height()-1, i, 0, SSD1306_WHITE);
    display.display();
    delay(1);
  }
  for(i=display.height()-1; i>=0; i-=4) {
    display.drawLine(0, display.height()-1, display.width()-1, i, SSD1306_WHITE);
    display.display();
    delay(1);
  }
  delay(250);

  display.clearDisplay();

  for(i=display.width()-1; i>=0; i-=4) {
    display.drawLine(display.width()-1, display.height()-1, i, 0, SSD1306_WHITE);
    display.display();
    delay(1);
  }
  for(i=display.height()-1; i>=0; i-=4) {
    display.drawLine(display.width()-1, display.height()-1, 0, i, SSD1306_WHITE);
    display.display();
    delay(1);
  }
  delay(250);

  display.clearDisplay();

  for(i=0; i<display.height(); i+=4) {
    display.drawLine(display.width()-1, 0, 0, i, SSD1306_WHITE);
    display.display();
    delay(1);
  }
  for(i=0; i<display.width(); i+=4) {
    display.drawLine(display.width()-1, 0, i, display.height()-1, SSD1306_WHITE);
    display.display();
    delay(1);
  }

  delay(1000); // Pause for 2 seconds
}

void testdrawrect(void) {
  display.clearDisplay();

  for(int16_t i=0; i<display.height()/2; i+=2) {
    display.drawRect(i, i, display.width()-2*i, display.height()-2*i, SSD1306_WHITE);
    display.display(); // Update screen with each newly-drawn rectangle
    delay(1);
  }

  delay(1000);
}

void testfillrect(void) {
  display.clearDisplay();

  for(int16_t i=0; i<display.height()/2; i+=3) {
    // The INVERSE color is used so rectangles alternate white/black
    display.fillRect(i, i, display.width()-i*2, display.height()-i*2, SSD1306_INVERSE);
    display.display(); // Update screen with each newly-drawn rectangle
    delay(1);
  }

  delay(1000);
}

void testdrawcircle(void) {
  display.clearDisplay();

  for(int16_t i=0; i<max(display.width(),display.height())/2; i+=2) {
    display.drawCircle(display.width()/2, display.height()/2, i, SSD1306_WHITE);
    display.display();
    delay(1);
  }

  delay(1000);
}

void testfillcircle(void) {
  display.clearDisplay();

  for(int16_t i=max(display.width(),display.height())/2; i>0; i-=3) {
    // The INVERSE color is used so circles alternate white/black
    display.fillCircle(display.width() / 2, display.height() / 2, i, SSD1306_INVERSE);
    display.display(); // Update screen with each newly-drawn circle
    delay(1);
  }

  delay(1000);
}

void testdrawroundrect(void) {
  display.clearDisplay();

  for(int16_t i=0; i<display.height()/2-2; i+=2) {
    display.drawRoundRect(i, i, display.width()-2*i, display.height()-2*i,
      display.height()/4, SSD1306_WHITE);
    display.display();
    delay(1);
  }

  delay(1000);
}

void testfillroundrect(void) {
  display.clearDisplay();

  for(int16_t i=0; i<display.height()/2-2; i+=2) {
    // The INVERSE color is used so round-rects alternate white/black
    display.fillRoundRect(i, i, display.width()-2*i, display.height()-2*i,
      display.height()/4, SSD1306_INVERSE);
    display.display();
    delay(1);
  }

  delay(1000);
}

void testdrawtriangle(void) {
  display.clearDisplay();

  for(int16_t i=0; i<max(display.width(),display.height())/2; i+=5) {
    display.drawTriangle(
      display.width()/2  , display.height()/2-i,
      display.width()/2-i, display.height()/2+i,
      display.width()/2+i, display.height()/2+i, SSD1306_WHITE);
    display.display();
    delay(1);
  }

  delay(1000);
}

void testfilltriangle(void) {
  display.clearDisplay();

  for(int16_t i=max(display.width(),display.height())/2; i>0; i-=5) {
    // The INVERSE color is used so triangles alternate white/black
    display.fillTriangle(
      display.width()/2  , display.height()/2-i,
      display.width()/2-i, display.height()/2+i,
      display.width()/2+i, display.height()/2+i, SSD1306_INVERSE);
    display.display();
    delay(1);
  }

  delay(1000);
}

void testdrawchar(void) {
  display.clearDisplay();

  display.setTextSize(1);      // Normal 1:1 pixel scale
  display.setTextColor(SSD1306_WHITE); // Draw white text
  display.setCursor(0, 0);     // Start at top-left corner
  display.cp437(true);         // Use full 256 char 'Code Page 437' font

  // Not all the characters will fit on the display. This is normal.
  // Library will draw what it can and the rest will be clipped.
  for(int16_t i=0; i<256; i++) {
    if(i == '\n') display.write(' ');
    else          display.write(i);
  }

  display.display();
  delay(1000);
}

void testdrawstyles(void) {
  display.clearDisplay();

  display.setTextSize(1);             // Normal 1:1 pixel scale
  display.setTextColor(SSD1306_WHITE);        // Draw white text
  display.setCursor(0,0);             // Start at top-left corner
  display.println(F("Hello, world!"));

  display.setTextColor(SSD1306_BLACK, SSD1306_WHITE); // Draw 'inverse' text
  display.println(3.141592);

  display.setTextSize(2);             // Draw 2X-scale text
  display.setTextColor(SSD1306_WHITE);
  display.print(F("0x")); display.println(0xDEADBEEF, HEX);

  display.display();
  delay(2000);
}

void testscrolltext(void) {
  display.clearDisplay();

  display.setTextSize(2); // Draw 2X-scale text
  display.setTextColor(SSD1306_WHITE);
  display.setCursor(10, 0);
  display.println(F("scroll"));
  display.display();      // Show initial text
  delay(100);

  // Scroll in various directions, pausing in-between:
  display.startscrollright(0x00, 0x0F);
  delay(1000);
  display.stopscroll();
  delay(1000);
  display.startscrollleft(0x00, 0x0F);
  delay(1000);
  display.stopscroll();
  delay(1000);
  display.startscrolldiagright(0x00, 0x07);
  delay(1000);
  display.startscrolldiagleft(0x00, 0x07);
  delay(1000);
  display.stopscroll();
  delay(1000);
}

void testdrawbitmap(void) {
  display.clearDisplay();

  display.drawBitmap(
    (display.width()  - LOGO_WIDTH ) / 2,
    (display.height() - LOGO_HEIGHT) / 2,
    logo_bmp, LOGO_WIDTH, LOGO_HEIGHT, 1);
  display.display();
  delay(1000);
}

#define XPOS   0 // Indexes into the 'icons' array in function below
#define YPOS   1
#define DELTAY 2

void testanimate(const uint8_t *bitmap, uint8_t w, uint8_t h) {
  int8_t f, icons[NUMFLAKES][3];

  // Initialize 'snowflake' positions
  for(f=0; f< NUMFLAKES; f++) {
    icons[f][XPOS]   = random(1 - LOGO_WIDTH, display.width());
    icons[f][YPOS]   = -LOGO_HEIGHT;
    icons[f][DELTAY] = random(1, 6);
    Serial.print(F("x: "));
    Serial.print(icons[f][XPOS], DEC);
    Serial.print(F(" y: "));
    Serial.print(icons[f][YPOS], DEC);
    Serial.print(F(" dy: "));
    Serial.println(icons[f][DELTAY], DEC);
  }

  for(;;) { // Loop forever...
    display.clearDisplay(); // Clear the display buffer

    // Draw each snowflake:
    for(f=0; f< NUMFLAKES; f++) {
      display.drawBitmap(icons[f][XPOS], icons[f][YPOS], bitmap, w, h, SSD1306_WHITE);
    }

    display.display(); // Show the display buffer on the screen
    delay(200);        // Pause for 1/10 second

    // Then update coordinates of each flake...
    for(f=0; f< NUMFLAKES; f++) {
      icons[f][YPOS] += icons[f][DELTAY];
      // If snowflake is off the bottom of the screen...
      if (icons[f][YPOS] >= display.height()) {
        // Reinitialize to a random position, just off the top
        icons[f][XPOS]   = random(1 - LOGO_WIDTH, display.width());
        icons[f][YPOS]   = -LOGO_HEIGHT;
        icons[f][DELTAY] = random(1, 6);
      }
    }
  }
}

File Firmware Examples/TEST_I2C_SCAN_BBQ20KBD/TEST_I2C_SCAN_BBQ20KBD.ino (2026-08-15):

#include <Arduino.h>
#include <Wire.h>

// BBQ20KBD
  #include <BBQ10Keyboard.h>
  #define BBQ10_KB_ADDR 0x1F
  BBQ10Keyboard keyboard;

// Define RP2040-Zero Hardware Pins
#define I2C_SDA_PIN 4
#define I2C_SCL_PIN 5

// Scanning Frequency Configuration
const uint32_t START_FREQ = 100000;  // 100 kHz (Standard Mode)
const uint32_t END_FREQ   = 1000000; // 1.0 MHz (Fast Mode Plus benchmark)
const uint32_t STEP_FREQ  = 100000;  // 100 kHz increments
const uint32_t BUS_TIMEOUT_US = 50000; // 50ms fault recovery timeout

// Tracks the maximum stable frequency for each discovered address
uint32_t max_stable_freq[128] = {0};
bool device_present_at_start[128] = {false};

// Force reset the physical I2C bus lines if a bus lockup occurs
void recoverBus() {
    pinMode(I2C_SDA_PIN, INPUT_PULLUP);
    pinMode(I2C_SCL_PIN, OUTPUT);
    
    // Clock out up to 9 cycles to free any hung slave devices
    for (int i = 0; i < 9; i++) {
        digitalWrite(I2C_SCL_PIN, LOW);
        delayMicroseconds(5);
        digitalWrite(I2C_SCL_PIN, HIGH);
        delayMicroseconds(5);
    }
    
    // Re-initialize Wire peripheral
    Wire.end();
}

void broadcastI2CReset() {
    Serial.println("  [->] Sending Global I2C General Call Reset Broadcast...");
    Wire.setClock(START_FREQ); // Drop back to a safe speed first
    Wire.beginTransmission(0x00); // 0x00 is the General Call Address
    Wire.write(0x06);             // 0x06 is the Reset Command byte
    Wire.endTransmission();
    delay(500); // Give emulated software slaves time to reboot their firmware
}

void keyScan() {
  const int keyCount = keyboard.keyCount();
  if (keyCount == 0)
    return;

  const BBQ10Keyboard::KeyEvent key = keyboard.keyEvent();
  String state = "pressed";
  if (key.state == BBQ10Keyboard::StateLongPress)
    state = "held down";
  else if (key.state == BBQ10Keyboard::StateRelease)
    state = "released";

  char buf[128];
  snprintf(buf, sizeof(buf), "key: '%c' (dec %d, hex %02x) %s", key.key, key.key, key.key, state.c_str());
  Serial.println(buf);

  // pressing 'b' turns off the backlight and pressing Shift+b turns it on
  if (key.state == BBQ10Keyboard::StatePress) {
    if (key.key == 'b') {
      keyboard.setBacklight(0);
    } else if (key.key == 'B') {
      keyboard.setBacklight(1.0);
    }
  }
}

void setup() {
    Serial.begin(115200);
    while (!Serial && millis() < 3000); // Wait for serial monitor
    // while (!Serial) { delay(10); } // Wait for serial monitor
    
    Serial.println("\n=================================");
    Serial.println("RP2040 I2C Stress & Boundary Scanner");
    Serial.println("=================================");
}

void loop() {
    Serial.println("\n--- Starting New Sweep Dynamic Analysis ---");
    memset(max_stable_freq, 0, sizeof(max_stable_freq));
    memset(device_present_at_start, 0, sizeof(device_present_at_start));

    // Phase 1: Baseline mapping at lowest reference speed
    Wire.setSDA(I2C_SDA_PIN);
    Wire.setSCL(I2C_SCL_PIN);
    Wire.begin();
    Wire.setClock(START_FREQ);
    Wire.setTimeout(BUS_TIMEOUT_US);

    Serial.print("Mapping baseline devices at ");
    Serial.print(START_FREQ / 1000);
    Serial.println(" kHz...");

    for (uint8_t address = 1; address < 127; address++) {
        Wire.beginTransmission(address);
        if (Wire.endTransmission() == 0) {
            device_present_at_start[address] = true;
            max_stable_freq[address] = START_FREQ;
            Serial.print("  -> Found responsive device at Address: 0x");
            if (address < 16) Serial.print("0");
            Serial.println(address, HEX);
        }
    }

    // Phase 2: Step up frequency to find individual device crash points
    for (uint32_t current_freq = START_FREQ + STEP_FREQ; current_freq <= END_FREQ; current_freq += STEP_FREQ) {
        Serial.print("\nTesting Bus Frequency: ");
        Serial.print(current_freq / 1000);
        Serial.println(" kHz");

        Wire.setClock(current_freq);

        for (uint8_t address = 1; address < 127; address++) {
            // Only test devices that were successfully found during baseline initialization
            if (!device_present_at_start[address]) continue;

            Wire.beginTransmission(address);
            uint8_t error = Wire.endTransmission();

            if (error == 0) {
                max_stable_freq[address] = current_freq; // Device stable at this threshold
            } else {
                Serial.print("  [!] Address 0x");
                if (address < 16) Serial.print("0");
                Serial.print(address, HEX);
                Serial.print(" FAILED with Hardware Code: ");
                Serial.println(error);
                
                // If a fatal timeout or bus error happens, clear the hardware line state
                if (error == 4 || error == 5) { 
                    Serial.println("  [!] Bus Lockup Detected. Initiating Bit-Bang Hardware Recovery Routine...");
                    recoverBus();
                    Wire.begin();
                    Wire.setClock(current_freq);
                    Wire.setTimeout(BUS_TIMEOUT_US);
                }
            }
        }
        delay(100); // Settling delay between frequency jumps
    }

    // Phase 3: Print Consolidated Maximum Performance Results
    Serial.println("\n=========================================");
    Serial.println("   FINAL MAXIMUM FREQUENCY REPORT       ");
    Serial.println("=========================================");
    bool found_any = false;
    
    for (uint8_t address = 1; address < 127; address++) {
        if (device_present_at_start[address]) {
            found_any = true;
            Serial.print("Device 0x");
            if (address < 16) Serial.print("0");
            Serial.print(address, HEX);
            Serial.print(" Max Operational Frequency: ");
            
            if (max_stable_freq[address] == END_FREQ) {
                Serial.print(">= ");
            }
            Serial.print(max_stable_freq[address] / 1000);
            Serial.println(" kHz");
        }
    }
    
    if (!found_any) {
        Serial.println("No operational I2C devices detected on the bus.");
    }
    Serial.println("=========================================");

    delay(5000); // Wait before starting the next full loop sweep

// BBQ20KBD
  // recoverBus();

  // Wire.setClock(100000);
  // Wire.setTimeout(BUS_TIMEOUT_US);

  broadcastI2CReset();

  keyboard.begin(BBQ10_KB_ADDR, &Wire); 
  keyboard.setBacklight(0.5f);

  while (1)
  {
    keyScan();
  }
}

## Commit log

2024-10-04 Add Demo Firmware for built-in RGB LED
2024-10-10 Rename schematic V1.0
2024-10-14 Begin V2 design improvements
    [SAO_Demo_Controller.kicad_pcb, SAO_Demo_Controller.kicad_sch]
2024-10-29 Update V2 schematics, docs, renders
    [SAO_Demo_Controller.kicad_pcb, SAO_Demo_Controller.kicad_sch]
2026-08-15 Add more datasheets
    [TPS63070 voltage output adjustment calcs.xlsx]
2026-08-15 Updated V2 design docs
    [SAO_Demo_Controller_V2_PCB.step]
2026-08-15 Add V3.0 to V3.2 Design files and schematic
    [SAO_Demo_Controller.kicad_pcb, SAO_Demo_Controller.kicad_sch, SAO_Demo_Controller_V3.0__bom-JLCPCB Assembly Order.xls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]
2026-08-16 Add special LiPo dedicated use note to schematic
    [SAO_Demo_Controller.kicad_sch]
2026-08-26 Correct V3 schematic PDF JP4 and 5 text
    [SAO_Demo_Controller.kicad_sch]
2026-08-26 Add datasheets
    [TPS61200 voltage output adjustment calcs.xlsx]
2026-08-26 Add V4 draft design
    [SAO_Demo_Controller.kicad_pcb, SAO_Demo_Controller.kicad_sch, SAO_Demo_Controller_V4.0_BOM-JLCPCB Assembly Order.xls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]
